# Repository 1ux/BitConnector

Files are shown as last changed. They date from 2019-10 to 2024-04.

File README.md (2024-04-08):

*„Jede Lösung eines Problems ist ein neues Problem.“ - J. W. Goehte*

# BitConnector

The BitConnector is a Complex Programmable Logic Device (CPLD) Board, optimized for hardware-based, digital prototype design on a breadboard.
The BitConnector is designed to represent a classic DIP chip in 2.54mm pitch with 2 * 20 pins. 
Configurations that are present in an HDL/schematic are transmitted via JTAG and stored permanently on the CPLD.

<table><tr>
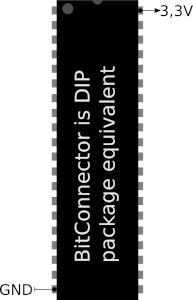
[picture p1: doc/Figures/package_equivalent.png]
BitConnector PCB layout
<td>    </td>
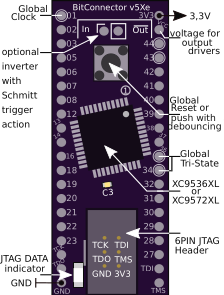
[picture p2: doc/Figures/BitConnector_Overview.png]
BitConnector
<td>    </td>
<td>   BitConnector circuit board </td>
<td>   BitConnector PCB Copper layer </td>
</tr></table>

## Usage & Documentation

Like every IC the BitConnector needs a clean operating voltage without ripple.
In practice, the following methods have proven successful:

- Protect the 3V3 Pin with 100nf and 10nf capacitors against GND.
- Keep the 3V3 and GND connections short and stable.
- Avoid long signal and test leads (up to 25 cm) to the inputs during operation.
- If you are having trouble getting a clean clock input, set „implementation template“ to „optimize density“ in Process Properties/Fitting
  or disable the special globally routed nets as described [here](https://web.archive.org/web/20210309172427/https://www.xilinx.com/support/documentation/sw_manuals/help/iseguide/mergedProjects/destech/html/cd_using_global_nets.htm)

Example experimental setup:

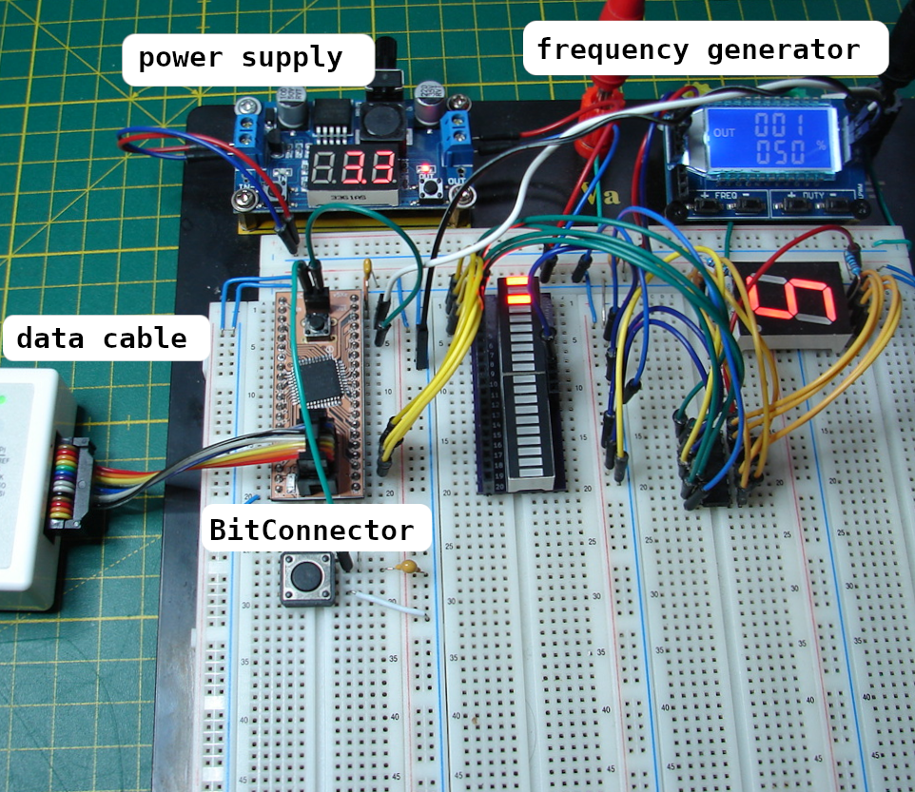
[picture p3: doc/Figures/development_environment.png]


- there is a detailed German board [documentation](doc/Board_Doc_German.pdf) :de:
- here is the preview for the [schematic](doc/schematic_v5Xe.pdf)
- files for board production have also been published in [Gerber](gerbers/gerbers_v5Xe.zip) format
- for a revision overview check: [changelog](changelog.txt)
- for all other questions, study the Kicad project.

| | | | | | |
| :- | :---: | :--- | :---: | :---: | :--- |
| **DIP-left**  | **CPLD-Pin** | **function** | **DIP-right**  | **CPLD-Pin** | **function** |
| 1  | 1 |GPIO, GCK3| 1 |  15,35 | 3V3/V<sub>ccINT</sub> |
| 2  | 2 | GPIO | 2 | 26 | VCC V<sub>ccIO</sub>  |
| 3  | 3 | GPIO | 3 | 44 | GPIO, GCK2 |
| 4  | 5 | GPIO | 4 | 43 | GPIO, GCK1 |
| 5  | 6 | GPIO | 5 | 42 | GPIO |
| 6  | 7 | GPIO | 6 | 41 | GPIO |
| 7  | 8 | GPIO | 7 | 40 | GPIO |
| 8  | 12 | GPIO | 8 | 39 | GPIO |
| 9  | 13 | GPIO | 9 | 38 | GPIO |
| 10 | 14 | GPIO | 10 | 37 | GPIO |
| 11 | 16 | GPIO | 11 | 36 | GPIO, GTS1 |
| 12 | 18 | GPIO | 12 | 34 | GPIO, GTS2 |
| 13 | 19 | GPIO | 13 | 32 | GPIO |
| 14 | 20 | GPIO | 14 | 31 | GPIO |
| 15 | 21 | GPIO | 15 | 30 | GPIO |
| 16 | 22 | GPIO | 16 | 29 | GPIO |
| 17 | 23 | GPIO | 17 | 28 | GPIO |
| 18 | 11 | TCK | 18 | 27 | GPIO |
| 19 | 24 | TDO | 19 | 9 | TDI |
| 20 |  17,25,4 | GND | 20 | 10 | TMS | |

Supplements and notes:

- **GPIO**=General Purpose In/Output, **GRS**=Global Reset, **GTS**=Global Tri-State, **GCK**=Global Clock, **TDI**=Test Data In, **TDO**=Test Data Out, **TCK**=Test Clk, **TMS**=Test Mode Select, V<sub>ccINT</sub>=Supply voltage internal logic, V<sub>ccIO</sub>=Supply voltage output driver
- Pin 33 is connected to the onboard push-button with GRS.
- With hardware debouncing, the push-button is high-active, otherwise it is low-active.

## Build

| | | | | |
| :- | :---: | :---: | :---: | :---: |
| No  | component |  value | quantity | package |
| 1 | Unpolarized capacitor | 100nF | 3 | 0603 |
| 2 | Unpolarized capacitor | 10nF | 3 | 0603 |
|  (3)  | Unpolarized capacitor | 100nF | 1 | 0603 |
|  (4)  | Resistor | 100K | 1 | 0805 |
|  (5)  | Resistor | 10K | 1 | 0805 |
| 6 | Resistor | 10K | 4 | 0805 |
| 7 | Resistor | 120 | 1 | 0805 |
| 8 | LED | blue | 1 | 1206 |
| 9 | Push button | 6 mm | 1 | THT |
| 10  | Pin Header 1x20 | 2.54 mm | 2 | vertical |
| 11  | IDC Header 2x3 | 2.54 mm | 1 | vertical |
|  (12) | Pin Socket 1x2 | 2.54 mm | 1 | vertical |
|  (13) | 74LVC2G14 | Schmitt-Tr  | 1 | SOT457 |
| 14  | XC9536XL/XC9572XL | CPLD | 1 | VQ44/VQG44  |

- The components without brackets correspond to the minimum configuration (without hardware debouncing).
- You can use the [XC9536XL](https://www.xilinx.com/support/documentation/data_sheets/ds058.pdf) or the more powerful [XC9572XL](https://www.xilinx.com/support/documentation/data_sheets/ds057.pdf) CPLD.
- The BitConverter was designed in a minimal configuration with commercially available components.
- The bracketed components are optional for hardware debouncing/Schmitt trigger action via [74LVC2G14](https://assets.nexperia.com/documents/data-sheet/74LVC2G14.pdf).
- If you make the board without hardware debouncing, please set the solderjumper J1.
- In addition to the schematic, the [Gerber](https://github.com/1ux/BitConnector/raw/master/gerbers/gerbers_v5X.zip) files for board production have also been published.

## Thanks to:

- Jeremy Heighway for mentoring English grammar and spelling.
- [Jana Weigel](https://janaweigel.wordpress.com/) for graphic design consulting, mentoring German grammar and spelling.
- [Lothar Miller](http://www.lothar-miller.de/) for PCB design consulting.
- [mikrocontroller.net](https://www.mikrocontroller.net/topic/492067) for failure analysis and life experience ;).

## Licence
This project by Michael Krause is distributed in the hope that it will be useful, but WITHOUT ANY WARRANTY.

This project is free: you can redistribute it and/or modify
it under the terms of [CC BY-SA 4.0](https://creativecommons.org/licenses/by-sa/4.0/deed.de)
Excluded from this licence is the logo(./doc/Figures/Logo.pdf).
Should you change or delete something, please remove the logo.

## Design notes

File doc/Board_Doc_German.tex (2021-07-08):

\documentclass{article}
\usepackage[utf8]{inputenc}
\usepackage[T1]{fontenc} % das Trennen der Umlaute
\usepackage[ngerman]{babel}
\usepackage{colortbl}
\usepackage{microtype}
\usepackage{graphicx}
\usepackage{grffile}
\usepackage{siunitx}  % für Einheiten
\usepackage{hyperref}
\usepackage{amsmath}
\sisetup{locale = DE,  
	separate-uncertainty,  
	range-units = brackets,  
	list-units = single,  
	per-mode=symbol-or-fraction} 
%\usepackage{subfig}
\usepackage{wrapfig}
\usepackage{tikz}
\usetikzlibrary{shapes}
\usepackage{xspace}

%-----------------------------------------------------------------------
%	BIBLIOGRAPHY
%-----------------------------------------------------------------------
\usepackage[style=numeric,sorting=none,backend=biber]{biblatex}
\addbibresource{Bibliographiedatei.bib}
%-----------------------------------------------------------------------

\graphicspath{{Figures/}}

\setlength{\parindent}{0em} 

\title{Dokumentation des BitConnector v5Xe}
\author{Michael Krause \\CC BY-SA 4.0 }

\date{\today}

\begin{document}
\maketitle
%\begin{figure}[!h]
%	\centering
%	\includegraphics[scale=0.06]{Logo}
%\end{figure}

%\thispagestyle{empty}
%\setlength{\unitlength}{1mm}
\begin{picture}(0,0)
\put(230,20){}
\end{picture} %

\section{Einführung}
Die noch immer andauernden Bemühungen der mikrokosmischen Minimierung von integriertern Schaltkreisen hat Integrationsdichten hervorgebracht, die traditionelle Schaltkreise wie einzelne Register, Zähler, ALUs oder Multiplexer vom Markt verschwinden ließen. Aus der Sicht des Endkonsumentenmarktes mag dieser Schritt folgerichtig sein, jedoch gibt es jenseits dessen noch immer das Bedürfnis auf der Register-Transfer Ebene oder darunter, Logikschaltkreise zu modellieren und zu realisieren. Dieses Bedürfnis kann beispielsweise der akademischen Lehre, dem Wunsch nach Parallelisierung oder der Vorgabe zeitkritischer Anwendungen entspringen. Obwohl es diesbezüglich eine Vielzahl von FPGAs und CPLD-Typen zur Abhilfe gibt, gestaltet sich der prototypische Aufbau auf einem Steckbrett mit Hilfe dieser Chips als nahezu unmöglich. Derartige Chips besitzen meist eine Vielzahl an Pins, die nicht im Dual in-line package (DIP) vorliegen. Der BitConnector versucht dieses Problem zu lösen.

\vspace{0.5cm}

%%Freiheitsgrade ....

\begin{wrapfigure}[14]{l}{0.50\textwidth}
		\vspace { -15pt }
	 
	\caption{BitConnector v5Xe}
	\label{fig:}
\end{wrapfigure}

Der BitConnector ist ein \textbf{C}omplex \textbf{P}rogrammable \textbf{L}ogic \textbf{D}evice, kurz \textbf{CPLD} Board, das für den  hardwarebasierten, digitalen Prototypenentwurf auf einem Steckboard optimiert wurde und zudem gesockelt auf andere Platinen aufgesetzt werden kann. Das Board ist so entworfen, dass es einen klassischen DIP Chip mit 2,54 mm Rastermaß und 2 * 20 Pins nachbildet. Konfigurationen, die etwa in einer HDL vorliegen, werden mittels JTAG übertragen und dauerhaft auf dem CPLD gespeichert.

\section{Eckdaten} 

BitConnector Board-Spezifikation
\begin{itemize}
	\item \textit{Anzahl der frei beschaltbaren Ein/Ausgänge:} \hspace{0.3cm} 33 GPIOs\footnote{\textbf{GPIO}=General Purpose In/Output, \textbf{GRS}=Global Reset, \textbf{GTS}=Global Tri-State, \textbf{GCK}=Global Clock, \textbf{TDI}=Test Data In, \textbf{TDO}=Test Data Out, \textbf{TCK}=Test Clk, \textbf{TMS}=Test Mode Select, \textbf{V\textsubscript{INT}}=Supply voltage internal logic, \textbf{V\textsubscript{IO}}=Supply voltage output driver} und ein Taster
	\item \textit{Gesamtanzahl der Pins:} \hspace{3.6cm} 2 Reihen * 20 Pins (2,54mm)
	\item \textit{kompatible CPLD-Varianten}: \hspace{2.8cm} XC95\textbf{72}XL sowie XC95\textbf{36}XL
	\item Max. Produktterme: \hspace{4.1cm} 1600 bei 72XL/800 bei~36XL
	\item \textit{IC-Package}: \hspace{5.3cm} VQ44 
\end{itemize}

Absolute, maximale Belastbarkeit:
\begin{itemize}
	\item \textit{Versorgungsspannung bezogen auf GND:} \hspace{1cm} -0,5V bis 4V
	\item \textit{IO-Pin Eingangsspannung bezogen auf GND:} \hspace{0.25cm} -0,5V bis 5,5V
	\item \textit{Max. Stromfluss bei max. 70 \si{\celsius} Chiptemp.}:\hspace{0.6cm} $\approx1,6A$ (siehe Kapitel \ref{sec:max_I})
\end{itemize}

Es wird empfohlen, Spannungen über und unter 3,3V($\pm 0,3V$) zu vermeiden!

\section{Pinbelegung BitConnector v5Xe}
\label{sec:Pins}

\begin{minipage}{0.54\textwidth}
	%\begin{table}[h]
	\begin{tabular}{c|c|c}
		DIP-links & CPLD Pin & Funktion\\
		\rowcolor[gray]{.8}	1 & 1 &	GPIO\footnotemark[1], GCK3\footnotemark[1]\\
		2 & 2 & GPIO\footnotemark[1]\\
		\rowcolor[gray]{.8}	3 & 3 & GPIO\footnotemark[1]\\
		4 & 5 & GPIO\footnotemark[1]\\
		\rowcolor[gray]{.8}	5 & 6 & GPIO\footnotemark[1]\\
		6 & 7 & GPIO\footnotemark[1]\\
		\rowcolor[gray]{.8}	7 & 8 & GPIO\footnotemark[1]\\
		8 & 12 & GPIO\footnotemark[1]\\
		\rowcolor[gray]{.8}	9 & 13 & GPIO\footnotemark[1]\\
		10 & 14 & GPIO\footnotemark[1]\\
		\rowcolor[gray]{.8}	11 & 16 & GPIO\footnotemark[1]\\
		12 &  18 & GPIO\footnotemark[1]\\
		\rowcolor[gray]{.8}	13 & 19 & GPIO\footnotemark[1]\\
		14 & 20 & GPIO\footnotemark[1]\\
		\rowcolor[gray]{.8}	15 & 21 & GPIO\footnotemark[1]\\
		16 & 22 & GPIO\footnotemark[1]\\
		\rowcolor[gray]{.8}	17 & 23 & GPIO\footnotemark[1]\\
		18 & 11 & TCK\footnotemark[1] JTAG\\
		\rowcolor[gray]{.8}	19 & 24 & TDO\footnotemark[1] JTAG\\	
		20 & 17,25,4 & GND
	\end{tabular}
	%\end{table}
\end{minipage}
\begin{minipage}{0.2\textwidth}
	\begin{tabular}{||c|c|c}
		DIP-rechts	& CPLD-Pin & Funktion\\
		\rowcolor[gray]{.8}	1		& 15,35 & 3V3/V\textsubscript{INT}\footnotemark[1] \\
		2		& 26 & 		V\textsubscript{IO}\footnotemark[1]\\
		\rowcolor[gray]{.8}	3	& 44 & GPIO, GCK2\footnotemark[1]\\
		4	& 43 & GPIO\footnotemark[1], GCK1\footnotemark[1]\\
		\rowcolor[gray]{.8}	5	& 42 & GPIO\footnotemark[1]\\
		6	& 41 & GPIO\footnotemark[1]\\
		\rowcolor[gray]{.8}	7	& 40 & GPIO\footnotemark[1]\\
		8	& 39 & GPIO\footnotemark[1]\\
		\rowcolor[gray]{.8}	9	& 38 & GPIO\footnotemark[1]\\
		10	& 37 & GPIO\footnotemark[1]\\
		\rowcolor[gray]{.8}	11	& 36 & GPIO\footnotemark[1], GTS1\footnotemark[1]\\
		12	& 34 & GPIO\footnotemark[1], GTS2\footnotemark[1]\\
		\rowcolor[gray]{.8}	13	& 32 & GPIO\footnotemark[1]\\
		14	& 31 & GPIO\footnotemark[1]\\
		\rowcolor[gray]{.8}	15	& 30 & GPIO\footnotemark[1]\\
		16	& 29 & GPIO\footnotemark[1]\\
		\rowcolor[gray]{.8}	17	& 28 & GPIO\footnotemark[1]\\
		18	& 27 & GPIO\footnotemark[1]\\
		\rowcolor[gray]{.8}	19		& 9 & TDI\footnotemark[1] JTAG\\	
		20		& 10 & TMS\footnotemark[1] JTAG
	\end{tabular}
\end{minipage}\\
\begin{minipage}{0.2\textwidth}
	\begin{tabular}{c|c|c}
		\rowcolor[gray]{.8} Taster \hphantom{\hspace*{0.38cm}} & \hphantom{\hspace*{0.55cm}} 33 \hphantom{\hspace*{0.5cm}} &  GRS, high active mit hardware debouncing, sonst low active
	\end{tabular}
\end{minipage}
\newpage

\section{Strom und Spannungsversorgung}

\subsection{Spannungsversorgnung V\textsubscript{ccINT}}
Wie bei traditionellen ICs auch, befindet sich die Betriebsspannung (V\textsubscript{ccINT}) des BitConnectors oben rechts  in Bezug zu GND (unten links).
Auf der Platine ist der V\textsubscript{ccINT} Pin mit „3V3“ beschriftet.
\\\\
\fbox{\parbox[c][0.5cm]{12cm}{V\textsubscript{ccINT} sollte 3.6V nicht übersteigen und 3V nicht unterschreiten. \autocite[3]{XC95_Spec}}}
\\\\
Der BitConnector besitzt aus Gründen der Flexibilität keinen Spannungsregler, es ist daher ratsam die Spezifikationen immer im Auge zu behalten. Ein weitere Fehlerquelle bezüglich {V\textsubscript{ccINT} ist eine unstabilisierten oder unsaubere Spannungsversorgung. In einem solchen Fall wird ein undefiniertes Verhalten bei getakteten/sequenziellen Schaltkreiskonfigurationen zu beobachten sein. 

\begin{figure}[!h]
	\begin{minipage}[!b]{.43\linewidth} % [b] => Ausrichtung an \caption
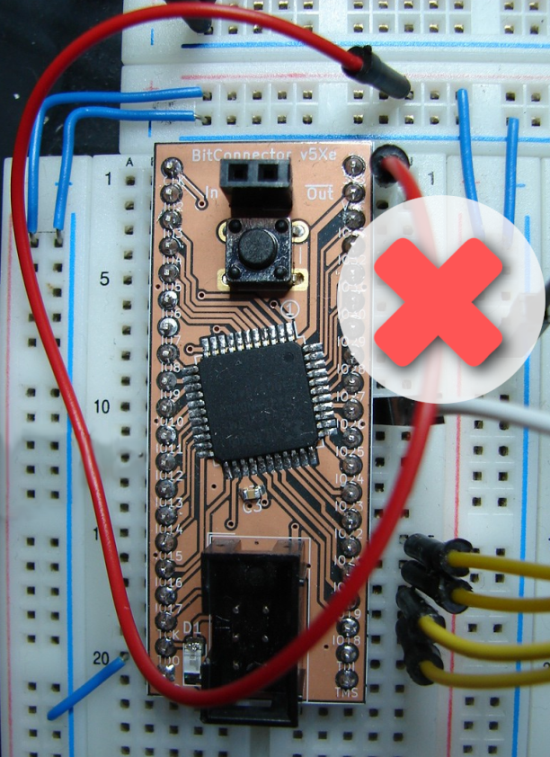
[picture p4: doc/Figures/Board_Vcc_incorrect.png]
		
		\caption{ungünstige Anbindung an die Versorgungsspannung}
		\label{fig:VCC_fail}
	\end{minipage}
	\hspace{.1\linewidth}% Abstand zwischen Bilder
	\begin{minipage}[!b]{.45\linewidth} % [b] => Ausrichtung an \caption
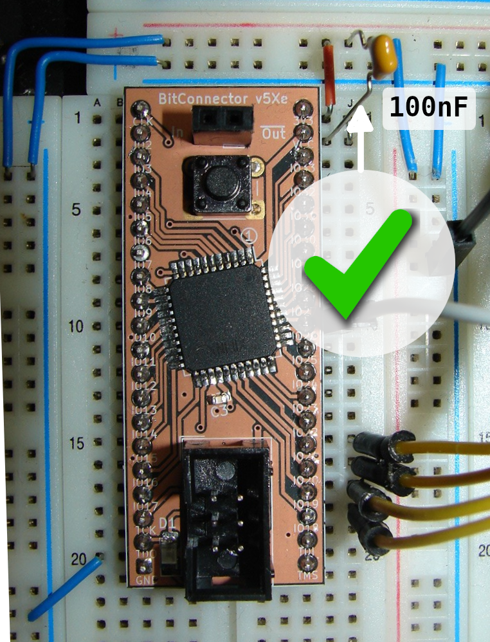
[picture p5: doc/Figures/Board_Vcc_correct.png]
		
		\caption{empfohlene Anbindung an die Versorgungsspannung}
		\label{fig:VCC_ok}
	\end{minipage}
\end{figure}

Obwohl ich nach der Xilinx Empfehlung \autocite{JTAG_Checklist} Bypass-Kondensatoren für verschiedene Frequenzbereiche auf dem BitConnector vorgesehen habe, um undefiniertem Verhalten vorzubeugen, sollten Sie immer einen zusätzlichen 100nF Kondensator direkt am 3V3 Pin des BitConnectors einsetzen (siehe Abbildung \ref{fig:VCC_ok}). Auch unnötig lange Kabel wie in Abbildung \ref{fig:VCC_fail}) sollten nach Möglichkeit vermieden werden.
%An dieser Stelle ist noch erwähnenswert, dass Sie nach \autocite[17]{XC95_maxI} einen „ stromlosen“ I/O-Pin mit einer maximalen Spannung von V\textsubscript{ccINT}+4V treiben dürfen.

\subsection{Definition der I/O Spannung über V\textsubscript{ccIO}}

Neben der Versorgungsspannung V\textsubscript{ccINT} existiert direkt darunterliegend der Pin V\textsubscript{ccIO}(siehe Kapitel \ref{sec:Pins}), welcher die Höhe der Pin-Ausgangsspannung definiert. Der V\textsubscript{ccIO} Pin ist auf der Platine mit „Vcc“ beschriftet. Sie können die Ausgangsspannung eines Pins in den Bereich zwischen 3,3V bis 2,5V über  V\textsubscript{ccIO} festlegen. Für eine Ausgangsspannung von 3,3 Volt sollte V\textsubscript{ccIO} zwischen 3V und 3,6V liegen. Wird dagegen eine Ausgangsspannung von 2,5V forciert, sollte V\textsubscript{ccIO} zwischen 2,3V und 2,7V liegen, siehe \autocite[3]{XC95_Spec}. Auf diese Weise kann die Ausgangsspannung aller Pins unabhängig von der Versorgungsspannung V\textsubscript{ccINT} eingestellt werden.

\subsection{Ausgangskennlinie eines XC9536XL CPLDs}
Sobald Sie einen GPIO-Pin des BitConnectors als Ausgang definieren und diesen mit einem Stromfluss belasten, in dem Sie beispielsweise eine LED ansteuern, sackt die Ausgangsspannung des entsprechenden Pins ab. Dieser Effekt geht auf den verwendeten CPLD zurück. Um eine Vorstellung zu erhalten, wie sich der treibende Strom zur Spannung verhält, habe ich einige stichpunktartig Messungen durchgeführt. Diese Messwerte sind in Abbildung \ref{fig:out_characteristics} mittels Bezierinterpolation zusammen gefasst und grafisch dargestellt.
Die Messreihe wurde über ein Fluke 87 III auf Pin 37 strom-/spannungsrichtig aufgenommen, V\textsubscript{ccINT} und V\textsubscript{ccIO} betrugen 3,3V. Obwohl es sich bei der Messung um einen XC9536XL CPLD handelt, ist es naheliegend, dass der XC9572XL eine sehr ähnliche Charakteristik zeigt. Verwunderlich ist, dass die Messreihe im Bereich zwischen 2V und 0V eine signifikant Abweichung (max. 10mA bei 0V) von der Xilinx-Spezifikation \autocite[6]{XC_Curves} aufweist.

\begin{figure}[!h]
	\centering
	
	\caption{Ausgangskennlinie eines XC9536XL}
	\label{fig:out_characteristics}
\end{figure}

\subsection{Maximaler Stromfluss $I_{max}$}
\label{sec:max_I}
Wer nach einem konkreten Wert bezüglich der maximal zulässigen Stromaufnahme im Datenblatt \autocite{XC95_Spec} des XC95\textbf{72}XL oder des XC95\textbf{36}XL sucht, wird keine derartige Angabe finden.
Zwar wird eine Abschätzung der zu erwartenden Stromaufnahme über eine Formel angegeben, welche die Frequenz, Anzahl der verwendeter Macrozellen u.s.w. mit einbezieht, jedoch bleibt ein maximal zulässiger Stromfluss $I_{max}$ unerwähnt. Der Hauptgrund dafür dürfte wohl an der variablen Umgebungstemperatur und in der individuell eingesetzten Kühlung des ICs liegen. Eine plausible Annahme für derartige Werte und die damit einhergehende maximale Stromaufnahme wäre von Xilinx an dieser Stelle jedoch angebracht gewesen und sei es nur, um eine erste Abschätzung zu bekommen.\\

Um eine solche Abschätzung der maximalen Stromaufnahme $I_{max}$ soll es nachfolgend gehen. Die Berechnung ist ein wenig müßig und führt über verschiedene Dokumentationen.
Zuerst wird die zu $I_{max}$ zugehörige Verlustleistung $P_d$ über folgende Ungleichung berechnet.\autocite[16]{XC95_maxI}: 
\begin{center}
	$T_{jmax} < (\Theta_{JC}*P_d)+T_a$
\end{center}

kurze Variablenbeschreibung:

\begin{itemize}
	\item $T_{jmax}$: Maximaltemperatur in \si{\celsius} bezogen auf das IC Package \\(70 \si{\celsius} für Kunststoff) \autocite[54]{Device_pkg}
	\item $\Theta_{JC}$: Wärmeflusswiderstand in $\si{\celsius}/[W]$ zwischen der Chipoberfläche und der Oberfläche des Gehäuses \autocite[53]{Device_pkg} (8.2 \si{\celsius}/W für 72/36 in VQ44)
	\item $P_d$: tatsächliche Leistung in [W]att, welche sich in Hitze äußert \autocite[16]{XC95_maxI}
	\item $T_a$: Umgebungstemperatur in \si{\celsius} (50 \si{\celsius})
\end{itemize}

Um $\Theta_{JC}$ nicht aufwendig durch eine Messung bestimmen zu müssen, bietet Xilinx eine Datenbank an \autocite{ThetaJC}. Für den XC95\textbf{72}XL/XC95\textbf{36}XL liegt dieser Wert bei 8.2 \si{\celsius}/W im VQ44 Package.\\\\
Zudem schlägt Xilinx für $T_{jmax}$ einen Wert von 70 \si{\celsius} für Kunststoffgehäuse vor. Dieser Wert ist ebenfalls für beide möglichen Chipvarianten angebracht.\\\\
Die Umgebungstemperatur des Chips wird vorsichtig mit 50 \si{\celsius} veranschlagt.\\\\
Ausgehend von diesen Annahmen berechnet sich die Verlustleistung nach \autocite[16]{XC95_maxI} wie folgt:

\begin{center}
	$70 \si{\celsius} = (8.2 \si{\celsius}/W*P_d)+50 \si{\celsius} \Rightarrow$\\
	$20 \si{\celsius} = (8.2 \si{\celsius}/W*P_d)\Rightarrow$\\
	$2,439 W = P_d$\\ %\vspace{0.5cm}
\end{center}

Weiter ist notwendig, die Verlustleistung in $P_d = P_{ddesign} + P_{dIO}$ aufzuschlüsseln.
$P_{ddesign}$ repräsentiert hierbei die Leistung ohne eine Last, also die Leistung die der Chip selbst für sich beansprucht, ohne einen Ausgang zu treiben. Dieser Wert sollte gemessen werden und lautet für den BitConnector rund 40mW. Wird dieser Wert aus Sicherheitsgründen verdoppelt, ist von rund 80mW auszugehen.\\\\
Somit gilt: 
\begin{center}
	$2,439 W = 80mW + P_{dIO}$
\end{center}

Um schlussendlich auf den gesuchten Wert $I_{max}$ zu kommen, wird folgende Formel nach \autocite[16]{XC95_maxI} herangezogen:

\begin{center}
	$I_{max} * (VCC - 1,85V) = P_d - P_{ddesign}$
\end{center}

Sicher fragen Sie sich, woher die 1,85V herstammen. Dieser Wert wurde über die Kennlinienfelder in \autocite[6]{XC_Curves} abgelesen und sagt aus, dass bei einem Stromfluss von 30mA, die Spannung des entsprechenden Ausgangs auf 1,85V absinkt.

Daraus folgt: 
\begin{center}
	$I_{max} * (3,3V - 1,85V) = 2,439 W - 0.08W \rightarrow$\\
	\underline{\underline{$I_{max}\approx 1,63A $}}
\end{center}
Der Wert $I_{max}$ sagt aus, dass bei einer I/O-Spannung von 1,85V und einer Stromstärke von 30mA pro Ausgang, eine Gesamtstromstärke von 1,63A erreicht wird. Hierbei liegt die Chiptemperatur $\leq $ der als kritisch angenommenen 70$\si{\celsius}$. Auffällig ist, dass die 1,63A in dieser Konstellation im Bitconnector nie erreicht werden können, da dieser nur 34 mögliche Ausgänge bietet. Mit den getroffenen Annahmen ist jedoch die Versorgung von $\frac{1,63A}{0,03A}\approx54$ Ausgänge möglich.\\\\
Bitte verlassen Sie sich nicht auf die angegebene Berechnung und überprüfen Sie auch die Quellen. Sollten Sie einen Fehler finden, wäre ich Ihnen sehr dankbar, wenn Sie mich diesbezüglich kontaktieren.

\newpage

\section{Hardware Entprellung}
Gelegentlich ist es sehr hilfreich, eine getaktete, sequenzielle Schaltung schrittweise über das Drücken eines Taster zu durchlaufen. Leider erzeugen so ziemlich alle handelsüblichen Taster ein sogenanntes „Prellen“, da die Kontakte des Tasters nicht sauber schließen oder öffnen. Ein solches Prellen führt zu einer unvorhersagbaren Abfolge von Signalimpulsen. Schauen Sie sich hierfür einmal die Abbildung \ref{fig:prellen_1} genauer an. 

\begin{figure}[!h]
	\centering
	
	\caption{Tastendruck am BitConnector ohne Entprellung}
	\label{fig:prellen_1}
\end{figure}

Hier wird ein einfacher Tastendruck über ein Oszillogramm grafisch veranschaulicht. Interessant ist der Bereich der fallende Flanke ab 80 Millisekunden, also ungefähr an der Stelle, an dem der Taster wieder losgelassen wird. Wenn Sie diesen Bereich kritisch betrachten, werden Sie bemerken, dass es bei ungefähr 92 Millisekunden bereits einen ungewollten Wechsel der Signalflanke gibt. Lassen Sie uns diesen Bereich mit der „Lupe“ in Abbildung \ref{fig:prellen_2} etwas näher betrachten.

\begin{figure}[!h]
	\centering
	
	\caption{Nahaufnahme der fallenden Flanke aus Abbildung \ref{fig:prellen_1}}
	\label{fig:prellen_2}
\end{figure}

Es ist erkennbar, dass der Signalpegel in Abbildung \ref{fig:prellen_2} bereits bei ungefähr 2 Millisekunden hin und herspringt und somit mehrere Flanken erzeugt. Diese Signalflanken sind bei sogenannten sequenziellen Schaltungen, die auf fallende oder steigende Flanken reagieren, problematisch. Eine einfache Zählerschaltung, die mit jedem Tastendruck „1“ hinzu addiert, wird augenscheinlich nicht funktionieren. So scheint es, als würde der Zähler einzelne Zählschritte beim Drücken oder Loslassen des Tasters überspringen. Mit einem höherwertigen Oszilloskop ließe sich der problematische Bereich noch näher untersuchen, was weitere Taktwechsel und somit weitere Zählimpulse mit nur einem Tastendruck aufdecken könnte. 
Da Sie bei CPLDs prinzipiell mit Ihren Flip-Flop-Ressourcen sehr haushalten müssen und keinen Mikrocontroller für eine Entprellroutine haben, wurde für den BitConnector eine Hardwareentprellung vorgesehen. 

\newpage

Sollte Ihr BitConnector mit dem 74LVC2G14 IC bestückt sein, so ist auch der Taster SW1 automatisch entprellt. Ein Tastendruck sollte dann wie in Abbildung \ref{fig:prellen_3} eine einzige und saubere Flanke erzeugen. 

\begin{figure}[!h]
	\centering
	
	\caption{Tastendruck am BitConnector mit Hardware-Entprellung}
	\label{fig:prellen_3}
\end{figure}

Sollte dies nicht der Fall sein, so können Sie auf Grundlage der nachfolgenden Erläuterungen eine eigene Hardwareentprellung nachschalten.

\subsection{Prinzip der Hardwareentprellung}
Da die vom Menschen erzeugten Frequenzen der Tastendrücke im Vergleich zum Prellen des Tasters sehr niedrig sind, ist es naheliegend einen Tiefpassfilter in Form eines RC-Gliedes dem Taster vorzuschalten. 
Dieser Tiefpass filtert die hochfrequenten Anteile des Prellens aus dem Tastendruck heraus. Das Prellen ist verschwunden. Es entsteht allerdings ein neues Problem. Da ein RC-Glied naturgemäß aus einem Widerstand und einem Kondensator besteht, durchläuft dieser Kondensator eine Ladespannung, die dem natürlichen Logarithmus sehr nahe kommt \autocite{RC}. Eine digitale Schaltung auf CMOS-Basis benötigt jedoch eine steile Signalflanke, also beispielsweise einen Signalwechsel von 0V auf direkt 3,3V. Andernfalls besteht die Gefahr, dass die Schaltung eine gewisse Zeit einen undefinierten Zustand annimmt. Auf Transistorebene kann dieser undefinierte Zustand gefährlich sein, da eine Transistorkonstellation, die es theoretisch so nicht geben sollte, plötzlich anfangen kann, den Strom zu leiten. Zudem werden Sie immer noch keine Freude beim auswerten des Tastenimpuls haben. Es ist daher nachdrücklich anzuraten, diese undefinierten Signalzustände in digitalen Schaltungen zu vermeiden. Dies geschieht hier mit Hilfe eines Schmitt-Triggers. Der Schmitt-Trigger soll verkürzt dargestellt, den undefinierten Spannungsbereich vor dem digitalen Eingang einer Schaltung über eine sogenannte „charakteristische Hysterese“ vermeiden. Sie können sich den Schmitt-Trigger in diesem Fall als den „eigentlichen Schalter“ vorstellen, der an seinem Ausgang immer einen steilen Pegel schaltet, während er am Eingang eine Kondenstorkennlinie „sieht“.
%Grafiken (Auch Schaltplan) und Berechnungen einfügen.

\section{Entwicklungsumgebung}

Momentan gibt es noch keine vollumfängliche und freie \autocite{FSF} Entwicklungsumgebung für Xilinx CPLDs, weshalb ich auf proprietäre Software der Firma Xilinx zurückgreifen muss.
Fraglicherweise bietet Xilinx in seiner aktuellen Entwicklungsumgebung „Vivado“ keine Unterstützung für CPLDs an, siehe \autocite[17]{Vivado}. Dennoch ist es möglich, mit der älteren Design Suite „ISE“, Xilinx CPLDs problemlos zu konfigurieren.
Mit einer Registrierung bei Xilinx erhalten Sie eine kostenlose Lizenz, mit derer Sie die ISE-Demo-Version auf eine Webpack-Version \autocite{ISE-Web} freischalten können. Diese Lizenz ist ausreichend, um alle CPLDs der XC9500 Serie ohne Einschränkungen zu konfigurieren.

\section{Die JTAG Schnittstelle via 6 Pin IDC-Header}

Für die Übertragung der HDL Konfigurationsdateien auf den BitConnector ist ein 6 Pin IDC-Stecker (JTAG Schnittstelle) im 2.54mm Rastermaß vorgesehen. Die 4 aktiven JTAG-Leitungen zur Datenübertragung sind:

\begin{enumerate}
	\item Pin TCK = Test Clock
	\item Pin TDI = Test Data In
	\item Pin TDO = Test Data Out
	\item Pin TMS = Test Mode Select
\end{enumerate}

\begin{figure}[!h]
	\centering
	
	\caption{Draufsicht JTAG Pin-Header (6 way IDC male connector)}
	\label{fig:pinheader}
\end{figure}

\newpage

Die Abbildung \ref{fig:pinheader} zeigt die Draufsicht dieses Steckers, welcher auf dem Board verlötet ist.
Innerhalb dieser Abbildung erkennen Sie eine „1“, die den ersten Pin markiert. Dieser Pin ist zur Orientierung dem JTAG Test-Takt zugeordnet. Um die Anfertigung eines eigenen Programmierkabels zu erleichtern, wird nachfolgend auch das passende Datenkabel illustriert. Ich möchte Sie ermutigen, die Anfertigung eines eigenen Kabels nicht zu fürchten. Die Minimalausrüstung sehen sie in Abbildung \ref{fig:cable_equipment}

\begin{figure}[!h]
	\centering
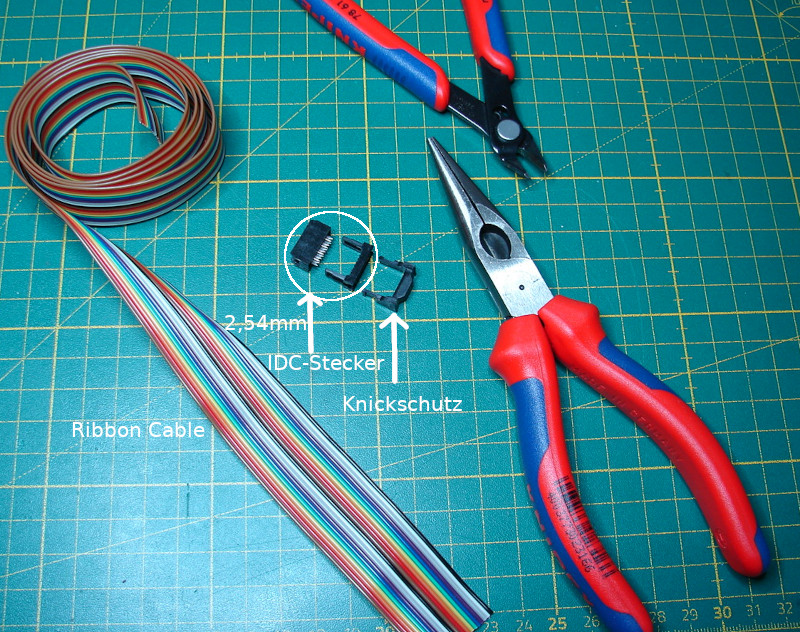
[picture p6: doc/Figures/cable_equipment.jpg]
	
	\caption{Werkzeug und Ribbon Cable + IDC-Stecker zum selber crimpen}
	\label{fig:cable_equipment}
\end{figure}

Da es mehrere Programmiergerät gibt, existieren somit mehrere Stecker-Möglichkeiten und Adapter.  In Abbildung \ref{fig:data_cable} erkennen Sie ein mögliches Datenkabel vom BitConnector zum Programmiergerät. Anders als in Abbildung \ref{fig:pinheader}, ist der 6 Pin Connector diesmal als Buchse ausgeführt und somit gespiegelt.

\begin{figure}[!h]
	\centering
	
	\caption{Programmierkabel HW-RIBBON14 zu 6 Pin IDC female}
	\label{fig:data_cable}
\end{figure}

Bei dem HW-RIBBON14 female connector hat sich Xilinx für eine eher exotische Buchse entschieden. Die Kette des Datenkabels sieht abstrakt zusammen gefasst folgendermaßen aus:
\vspace{0.5cm}
\begin{center}
	PC<->USB-Kable<->Programmierer<->Programmierkabel<->BitConnector
\end{center}

\vspace{0.5cm}

\newpage

Falls Sie kein passendes Kabel zur Hand haben, können Sie die herausgeführten JTAG Pins von den beiden Stiftleisten über ein Steckbrett abgreifen(rote Markierung).

\begin{figure}[!h]
	\centering
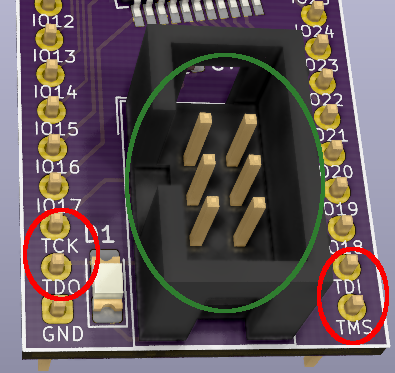
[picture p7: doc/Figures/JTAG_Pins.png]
	
	\caption{Die JTAG Schnittstelle, einmal rot umkreist als Stiftleisten und grün umkreist als IDC Header ausgeführt}
	\label{fig:JTAG_Pins}
\end{figure}

Sofern Sie mehrere BitConnectoren auf einer Platine gesockelt haben, bieten sich die Pins der Stiftleisten ebenfalls an, um die CPLDs mit nur einer herausgeführten Schnittstelle sequenziell zu konfigurieren.
\subsection{JTAG Programmiergerät}
Für die Ansteuerung der JTAG-Schnittstelle wird ein Programmiergerät benötigt. 
Hier gibt es mehrere Lösungen mit unterschiedlichen Funktionsumfang. Verbreitet sind 4 Versionen des Xilinx Platform Cable USB I/II. Dabei entfallen bereits 3 Versionen auf das Platform Cable I: 
\begin{itemize}
	\item \textbf{DLC9G} (neuste Version bezüglich Platform Cable I)
	\item \textbf{DLC9LP} (Vorgänger des DLC9G)
	\item \textbf{DLC9} (älteste Version)
\end{itemize}

\newpage

Zu diesen 3 Versionen schreibt Xilinx u.a.: „\textit{The DLC9G and legacy DLC9LP cable models draw less than 100 mA from the host USB port. The legacy DLC9 cable model requires 230 mA to operate in USB 2.0 Hi-Speed mode or 150 mA to operate in USB 2.0/1.1 full-speed mode.}“ \autocite[2]{Platform_Cable}\\\\
Das Xilinx Platform Cable USB II wird momentan unter der Versionsbezeichnung „\textbf{DLC10}“ gehandelt.
Die hohen Verbreitung dieser Programmiergeräte hat dazu beigetragen, dass es selbige auch als preisgünstige Nachbauten von anderen Herstellern zu einem Zehntel des Preises gibt.

\begin{figure}[!h]
	\centering
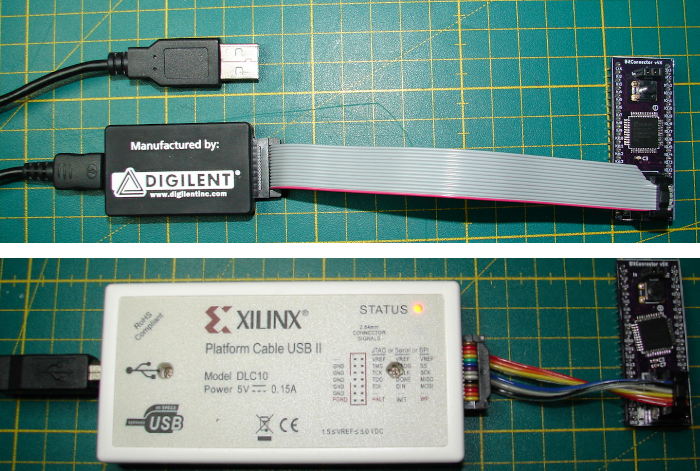
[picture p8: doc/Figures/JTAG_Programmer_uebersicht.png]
	
	\caption{oben: XUP USB-JTAG Programming Cable
		\\\hspace*{2cm} unten: Platform Cable USB II DLC10}
	\label{fig:JTAG_Cable}
\end{figure}

Als Alternative zum „Platform Cable I/II“ existiert eine kleine und günstigere Variante aus dem „Xilinx University Program“ dass die Bezeichnung „XUP USB-JTAG Programming Cable“ trägt. Sie können es nachfolgend in Abbildung \ref{fig:JTAG_Cable} erkennen. Allerdings scheint diese Variante mit dem heutigen Preisverfall des Platform Cables I/II wenig attraktiv zu sein. 
Der Vollständigkeit halber soll an dieser Stelle noch das \textbf{DLC7}/Parallel Cable IV erwähnt werden, dass jedoch in der neuen Entwicklungsumgebung von Xilinx/Vivado nicht mehr unterstützt wird \autocite{AR_54136} und aufgrund der „ausgestorbenen“ parallelen Schnittstelle bei Anwendern ebenfalls nur mehr selten anzutreffen sein dürfte. Wenn Sie keinen Wert auf Zusatzfunktionen wie „SPI PROM Support, ChipScope oder AES-Cryptographic“ legen, sollte die Wahl des Programmers eine untergeordnete Rolle spielen.

\newpage

\subsection{Offene JTAG Hardware-/Softwarelösungen für Xilinx}
Es gibt einige Projekte, die sich darum bemühen, alternative und offene JTAG Hardware-/Softwarelösungen für Xlinix Produkte anzubieten.
Um ein CPLD/FPGA zu konfigurieren, wird ein Mikrocontroller (JTAG-Programmiergerät) benötigt, der den JTAG Standard „IEEE 1149.1“ und eventuelle herstellerspezifische Abweichungen implementiert. 
Um mit diesem Mikrocontroller kommunizieren zu können, wird weiter eine PC-Software (JTAG Client) benötigt, welche die HDL synthetisierte Konfiguration (im XSVF Format) an diesen Mikrocontroller überträgt. Der Mikrocontroller nimmt letztlich über das vom PC aus übertragene XSVF Format die Konfiguration des CPLD/FPGA mittels JTAG vor.

\begin{figure}[!h]
	\centering
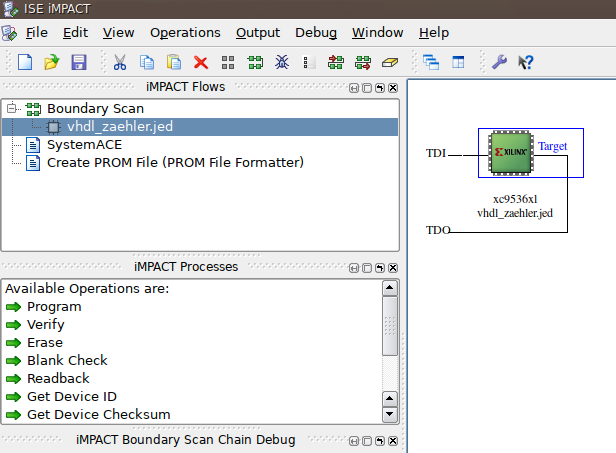
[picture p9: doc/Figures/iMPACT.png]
	
	\caption{Das proprietäre iMPACT überträgt und verifiziert die HDL Konfiguration (über ein JTAG Programmiergerät) auf dem CPLD oder FPGE}
	\label{fig:iMPACT}
\end{figure}

Um aber auf die offenen Alternativen hinzuweisen, soll hier die Lib(X)SVF von Clifford Wolf\autocite{LibXSVF} Erwähnung finden. Lib(X)SVF ist eine C-Bibliothek zur Implementierung/Umsetzung von JTAG-Programmiergeräten mittels XSVF/SVF Format. Eine konkrete Implementierung ist beispielsweise das „clujtag“ Projekt, wobei clujtag \autocite{clujtag} die Firmware eines einfachen AVR basierten Programmiergeräts bildet und clujtag-client \autocite{clujtag-client} eine kommandozeilenbasierte Alternative zu Xilnix iMPACT darstellt.
In welchen Umfang diese und andere Projekte heute tragfähig sind, kann ich bisher nicht einschätzen.

\newpage
\printbibliography
\end{document}

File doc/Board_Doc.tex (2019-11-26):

\documentclass{article}
\usepackage[utf8]{inputenc}
\usepackage[T1]{fontenc} % das Trennen der Umlaute
\usepackage[ngerman]{babel}
\usepackage{colortbl}
\usepackage{microtype}
\usepackage{graphicx}
\usepackage{grffile}
\usepackage{siunitx}  % für Einheiten
\usepackage{hyperref}
\usepackage{amsmath}
\sisetup{locale = DE,  
	separate-uncertainty,  
	range-units = brackets,  
	list-units = single,  
	per-mode=symbol-or-fraction} 
%\usepackage{subfig}
\usepackage{wrapfig}
\usepackage{tikz}
\usetikzlibrary{shapes}
\usepackage{xspace}

%-----------------------------------------------------------------------
%	BIBLIOGRAPHY
%-----------------------------------------------------------------------
\usepackage[style=numeric]{biblatex}
\addbibresource{Bibliographiedatei.bib}
%-----------------------------------------------------------------------

\graphicspath{{Figures/}}

\setlength{\parindent}{0em} 

\title{Dokumentation des BitConnector v4X}
\author{Michael Krause \\CC BY-SA 4.0 (except logo)}

\date{\today}

\begin{document}
\maketitle
%\begin{figure}[!h]
%	\centering
%	\includegraphics[scale=0.06]{Logo}
%\end{figure}

%\thispagestyle{empty}
%\setlength{\unitlength}{1mm}
\begin{picture}(0,0)
\put(270,38){}
\end{picture} %

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

\vspace{0.5cm}

%%Freiheitsgrade ....

\begin{wrapfigure}[14]{l}{0.50\textwidth}
		\vspace { -15pt }
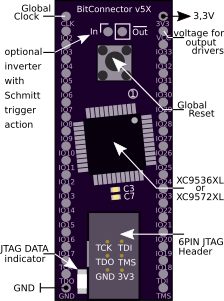
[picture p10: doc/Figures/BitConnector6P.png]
	 
	\caption{BitConnector v4X}
	\label{fig:}
\end{wrapfigure}

Der BitConnector ist ein \textbf{C}omplex \textbf{P}rogrammable \textbf{L}ogic \textbf{D}evice, kurz \textbf{CPLD} Board, das für den  hardwarebasierten, digitalen Prototypenentwurf auf einem Steckboard optimiert wurde und zudem gesockelt auf andere Platinen aufgesetzt werden kann. Das Board ist so entworfen, dass es einen klassischen DIP Chip mit 2,54 mm Rastermaß und 2 * 20 Pins nachbildet. Konfigurationen, die etwa in einer HDL vorliegen, werden mittels JTAG übertragen und dauerhaft auf dem CPLD gespeichert.

\section{Eckdaten} 

BitConnector Board-Spezifikation
\begin{itemize}
	\item \textit{Anzahl der frei beschaltbaren Ein/Ausgänge:} \hspace{0.3cm} 33
	\item \textit{Gesamtanzahl der Pins:} \hspace{3.6cm} 2 Reihen * 20 Pins (2,54mm)
	\item \textit{kompatible CPLD-Varianten}: \hspace{2.8cm} XC95\textbf{72}XL sowie XC95\textbf{36}XL
	\item Max. Produktterme: \hspace{4.1cm} 1600 bei 72XL/800 bei~36XL
	\item \textit{IC-Package}: \hspace{5.3cm} VQ44 
\end{itemize}

Absolute, maximale Belastbarkeit:
\begin{itemize}
	\item \textit{Versorgungsspannung bezogen auf GND:} \hspace{1cm} -0,5V bis 4V
	\item \textit{Eingangsspannung bezogen auf GND:} \hspace{1.45cm} -0,5V bis 5,5V
	\item \textit{Max. Stromfluss bei max. 70 \si{\celsius} Chiptemp.}:\hspace{0.6cm} $\approx1,6A$ (siehe Kapitel \ref{sec:max_I})
\end{itemize}

Es wird empfohlen, Spannungen über und unter 3,3V($\pm 0,3V$) zu vermeiden!

\section{Pinbelegung BitConnector v3X}
\label{sec:Pins}

\begin{minipage}{0.55\textwidth}
	%\begin{table}[h]
	\begin{tabular}{l|c|c|l}
		Nr & DIP-links	& CPLD-Pin & Bemerkung\\
		\rowcolor[gray]{.8}	1 & CLK		& 1 &	GCK3\\
		2 & IO2		& 2 &\\
		\rowcolor[gray]{.8}	3 & IO3		& 3 &\\
		4 & IO4		& 5 &\\
		\rowcolor[gray]{.8}	5 & IO5		& 6 &\\
		6 & IO6		& 7 &\\
		\rowcolor[gray]{.8}	7 & IO7		& 8 &\\
		8 & IO8		& 12 &\\
		\rowcolor[gray]{.8}	9 & IO9		& 13 &\\
		10 & IO10	& 14 &\\
		\rowcolor[gray]{.8}	11 & IO11	& 16 &\\
		12 & IO12	& 18 &\\
		\rowcolor[gray]{.8}	13 & IO13	& 19 &\\
		14 & IO14	& 20 &\\
		\rowcolor[gray]{.8}	15 & IO15	& 21 &\\
		16 & IO16	& 22 &\\
		\rowcolor[gray]{.8}	17 & IO17	& 23 &\\
		18 & TCK		& 11 &	JTAG\\
		\rowcolor[gray]{.8}	19 & TDO		& 24 &	JTAG\\	
		20 & GND		& 17,25,4 & 	 
	\end{tabular}
	%\end{table}
\end{minipage}
\begin{minipage}{0.2\textwidth}
	\begin{tabular}{||c|c|l}
		DIP-rechts	& CPLD-Pin & Bemerkung\\
		\rowcolor[gray]{.8}	3V3		& 15,35 &	V\textsubscript{ccINT} \\
		VCC		& 26 & 		V\textsubscript{ccIO}\\
		\rowcolor[gray]{.8}	IO33	& 44 &		GCK2\\
		IO32	& 43 &		GCK1\\
		\rowcolor[gray]{.8}	IO31	& 42 &\\
		IO30	& 41 &\\
		\rowcolor[gray]{.8}	IO29	& 40 &\\
		IO28	& 39 &\\
		\rowcolor[gray]{.8}	IO27	& 38 &\\
		IO26	& 37 &\\
		\rowcolor[gray]{.8}	IO25	& 36 &		GTS1\\
		IO24	& 34 &							GTS2\\
		\rowcolor[gray]{.8}	IO23	& 32 &\\
		IO22	& 31 &\\
		\rowcolor[gray]{.8}	IO21	& 30 &\\
		IO20	& 29 &\\
		\rowcolor[gray]{.8}	IO19	& 28 &\\
		IO18	& 27 &\\
		\rowcolor[gray]{.8}	TDI		& 9 &		JTAG\\	
		TMS		& 10 & 		JTAG 
	\end{tabular}
\end{minipage}
\\\\\\
Pin 33 ist an dem Taster SW1 fest verdrahtet, zudem ist Pin 33 auch GRS
(GSR=Global Reset, GTS=Global Tri-State, GCK=Global Clock).
%GPIO (General Purpose Input/Output)
\newpage

\section{Strom und Spannungsversorgung}

\subsection{Spannungsversorgnung VCC\textsubscript{INT}}
Wie bei traditionellen ICs auch, befindet sich die Betriebsspannung (VCC\textsubscript{INT}) des BitConnectors oben rechts  in Bezug zu GND (unten links).
\\\\
Die Betriebsspannung sollte 3.6V nicht übersteigen und 3V nicht unterschreiten. \autocite[3]{XC95_Spec}
\\\\
Es wurde bewusst auf einen Spannungsregler verzichtet, um den zu treibenden Ausgangsstrom nicht zu begrenzen. Diese Entscheidung schafft zwar Flexibilität, verlagert aber die Verantwortung auf eine korrekte Spannungsversorgung auf die externe Peripherie.\\
An dieser Stelle ist noch erwähnenswert, dass Sie nach \autocite[17]{XC95_maxI} einen „ stromlosen“ I/O-Pin mit einer maximalen Spannung von VCC\textsubscript{INT}+4V treiben dürfen.

\subsection{Definition der I/O Spannung über VCC\textsubscript{IO}}

Neben der Versorgungsspannung VCC\textsubscript{INT} existiert direkt darunterliegend der Pin VCC\textsubscript{IO}(siehe Kapitel \ref{sec:Pins}), welcher die Höhe der Pin-Ausgangsspannung definiert. Sie können die Spannung der Ausgänge bei einem h-Pegel auf 3,3V oder auf 2,5V setzen. Für eine Ausgangsspannung von 3,3 Volt, sollte VCC\textsubscript{IO} zwischen 3V und 3,6V liegen. Wird dagegen eine Ausgangsspannung von 2,5V forciert, sollte VCC\textsubscript{IO} zwischen 2,3V und 2,7V liegen \autocite[3]{XC95_Spec}

\subsection{Ausgangskennlinie eines XC9536XL CPLDs}
Sobald Sie einen Pin des BitConnectors mit einem Stromfluss belasten, in dem Sie beispielsweise eine LED ansteuern, sackt die Ausgangsspannung des entsprechenden I/O-Pins ab. Dieser Effekt geht auf den verwendeten CPLD zurück. Um nun eine Vorstellung zu erhalten, wie sich der treibende Strom zur Spannung verhält, hat der Autor einige stichpunktartig Messungen durchgeführt. Diese Messwerte sind in Abbildung \ref{fig:out_characteristics} mittels Bezierinterpolation grafisch dargestellt.
Die Messreihe wurde über ein Fluke 87 III , strom-/spannungsrichtig aufgenommen, VCC\textsubscript{INT} und VCC\textsubscript{IO} betrugen 3,3V, IO33 (CPLD Pin 44) war der (einzige) belastete Ausgang. Obwohl es sich bei der Messung um einen XC9536XL CPLD handelt, ist es naheliegend, dass der XC9572XL eine sehr ähnliche Charakteristik zeigt. Verwunderlich ist, dass die Messreihe teilweise signifikant von der Xilinx-Spezifikation \autocite[6]{XC_Curves} abweicht.  Dennoch wurde in Kapitel \ref{sec:max_I} auf die von Xilinx veröffentlichte Spezifikation zurück gegriffen.

\newpage

\begin{figure}[!h]
	\centering
	
	\caption{Ausgangskennlinie eines XC9536XL}
	\label{fig:out_characteristics}
\end{figure}

\subsection{Maximaler Stromfluss $I_{max}$}
\label{sec:max_I}
Wer nach einem konkreten Wert bezüglich der maximal zulässigen Stromaufnahme im Datenblatt \autocite{XC95_Spec} des XC95\textbf{72}XL oder des XC95\textbf{36}XL sucht, wird keine derartige Angabe finden.
Zwar wird eine Abschätzung der zu erwartenden Stromaufnahme über eine Formel angegeben, welche die Frequenz, Anzahl der verwendeter Macrozellen u.s.w. mit einbezieht, jedoch bleibt ein maximal zulässiger Stromfluss $I_{max}$ unerwähnt. Der Hauptgrund dafür dürfte wohl an der variablen Umgebungstemperatur und in der individuell eingesetzten Kühlung des ICs liegen. Eine plausible Annahme für derartige Werte und die damit einhergehende maximale Stromaufnahme wäre von Xilinx an dieser Stelle jedoch angebracht gewesen und sei es nur, um eine erste Abschätzung zu bekommen.\\

Um eine solche Abschätzung der maximalen Stromaufnahme $I_{max}$ soll es nachfolgend gehen. Die Berechnung ist ein wenig müßig und führt über verschiedene Dokumentationen.
Zuerst wird die zu $I_{max}$ zugehörige Verlustleistung $P_d$ über folgende Ungleichung berechnet.\autocite[16]{XC95_maxI}: 
\begin{center}
	$T_{jmax} < (\Theta_{JC}*P_d)+T_a$
\end{center}

\newpage

kurze Variablenbeschreibung:

\begin{itemize}
	\item $T_{jmax}$: Maximaltemperatur in \si{\celsius} bezogen auf das IC Package \\(70 \si{\celsius} für Kunststoff) \autocite[54]{Device_pkg}
	\item $\Theta_{JC}$: Wärmeflusswiderstand in $\si{\celsius}/[W]$ zwischen der Chipoberfläche und der Oberfläche des Gehäuses \autocite[53]{Device_pkg} (8.2 \si{\celsius}/W für 72/36 in VQ44)
	\item $P_d$: tatsächliche Leistung in [W]att, welche sich in Hitze äußert \autocite[16]{XC95_maxI}
	\item $T_a$: Umgebungstemperatur in \si{\celsius} (50 \si{\celsius})
\end{itemize}

Um $\Theta_{JC}$ nicht aufwendig durch eine Messung bestimmen zu müssen, bietet Xilinx eine Datenbank an \autocite{ThetaJC}. Für den XC95\textbf{72}XL/XC95\textbf{36}XL liegt dieser Wert bei 8.2 \si{\celsius}/W im VQ44 Package.\\\\
Zudem schlägt Xilinx für $T_{jmax}$ einen Wert von 70 \si{\celsius} für Kunststoffgehäuse vor. Dieser Wert ist ebenfalls für beide möglichen Chipvarianten angebracht.\\\\
Die Umgebungstemperatur des Chips wird vorsichtig mit 50 \si{\celsius} veranschlagt.\\\\
Ausgehend von diesen Annahmen berechnet sich die Verlustleistung nach \autocite[16]{XC95_maxI} wie folgt:

\begin{center}
	$70 \si{\celsius} = (8.2 \si{\celsius}/W*P_d)+50 \si{\celsius} \Rightarrow$\\
	$20 \si{\celsius} = (8.2 \si{\celsius}/W*P_d)\Rightarrow$\\
	$2,439 W = P_d$\\ \vspace{0.5cm}
\end{center}
	Weiter ist notwendig, die Verlustleistung in $P_d = P_{ddesign} + P_{dIO}$ aufzuschlüsseln.
$P_{ddesign}$ repräsentiert hierbei die Leistung ohne eine Last, also die Leistung die der Chip selbst für sich beansprucht, ohne einen Ausgang zu treiben. Dieser Wert sollte gemessen werden und lautet für den BitConnector rund 40mW. Wird dieser Wert aus Sicherheitsgründen verdoppelt, ist von rund 80mW auszugehen.\\\\
Somit gilt: 
\begin{center}
	$2,439 W = 80mW + P_{dIO}$
\end{center}

Um schlussendlich auf den gesuchten Wert $I_{max}$ zu kommen, wird folgende Formel nach \autocite[16]{XC95_maxI} herangezogen:

\begin{center}
	$I_{max} * (VCC - 1,85V) = P_d - P_{ddesign}$
\end{center}

Sicher fragen Sie sich, woher die 1,85V herstammen. Dieser Wert wurde über die Kennlinienfelder in \autocite[6]{XC_Curves} abgelesen und sagt aus, dass bei einem Stromfluss von 30mA, die Spannung des entsprechenden Ausgangs auf 1,85V absinkt.

Daraus folgt: 
\begin{center}
	$I_{max} * (3,3V - 1,85V) = 2,439 W - 0.08W \rightarrow$\\
	\underline{\underline{$I_{max}\approx 1,63A $}}
\end{center}
Der Wert $I_{max}$ sagt aus, dass bei einer I/O-Spannung von 1,85V und einer Stromstärke von 30mA pro Ausgang, eine Gesamtstromstärke von 1,63A erreicht wird. Hierbei liegt die Chiptemperatur $\leq $ der als kritisch angenommenen 70$\si{\celsius}$. Auffällig ist, dass die 1,63A in dieser Konstellation im Bitconnector nie erreicht werden können, da dieser nur 34 mögliche Ausgänge bietet. Mit den getroffenen Annahmen ist jedoch die Versorgung von $\frac{1,63A}{0,03}\approx54$ Ausgänge möglich.\\\\
Bitte verlassen Sie sich nicht auf die angegebene Berechnung und überprüfen Sie auch die Quellen. Sollten Sie einen Fehler finden, wäre ich Ihnen sehr dankbar, wenn Sie mich diesbezüglich kontaktieren.

\section{Hardware Entprellung}
Gelegentlich ist es sehr wichtig, eine getaktete, sequenzielle Schaltung schrittweise, manuell über einen Taster zu durchlaufen. Leider erzeugen so ziemlich alle handelsüblichen Taster ein Prellen. Ein solches Prellen führt zu einer undefinierten Abfolge von Signalimpulsen. Da Sie bei CPLDs prinzipiell mit Ihren Flip-Flop-Ressourcen sehr haushalten müssen, wurde für den BitConnector eine Hardwareentprellung vorgesehen. Sofern Ihre Ausführung mit dem 74LVC2G14 IC bestückt ist, ist der Taster SW1 auf dem Board automatisch entprellt. Sollte dies nicht der Fall sein, so können Sie auf Grundlage der nachfolgenden Erläuterungen, eine eigene Hardwareentprellung nachschalten.
\subsection{Prinzip der Hardwareentprellung}
Da die vom Menschen erzeugten Frequenzen der Tastendrücke im Vergleich zum Prellen des Tasters sehr niedrig sind, wurde ein Tiefpassfilter in Form eines RC-Gliedes dem Taster nachgeschaltet. 
Dieser Tiefpass filtert die hochfrequenten Anteile des Prellens aus dem Tastendruck heraus. Das Prellen ist verschwunden. Es entsteht allerdings ein neues Problem. Da ein RC-Glied naturgemäß aus einem Widerstand und einem Kondensator besteht, durchläuft dieser Kondensator eine Ladespannung, die dem natürlichen Logarithmus sehr nahe kommt (siehe beispielsweise \autocite{RC}). Eine digitale Schaltung auf CMOS-Basis benötigt jedoch eine steile Signalflanke, also beispielsweise einen Signalwechsel von 0V auf direkt 3,3V. Andernfalls besteht die Gefahr, dass die Schaltung in einen undefinierten Zustand abrutscht. Auf Transistorebene kann dieser undefinierte Zustand sehr gefährlich sein, da eine Transistorkonstellation, die es theoretisch so nicht geben sollte, plötzlich anfangen kann, den Strom zu leiten. Zudem werden Sie immer noch keinen auswertbaren Tastenimpuls erwarten können. Es ist daher zwingend anzuraten, diese undefinierten Signalzustände in digitalen Schaltungen zu vermeiden. Dies geschieht hier mit Hilfe eines Schmitt-Triggers. Der Schmitt-Trigger soll verkürzt dargestellt, den undefinierten Spannungsbereich auf einen definierten high- oder low- Pegel zurück bringen. Die charakteristische Hysterese eines Schmitt-Triggers ist dafür verantwortlich, den undefinierten Spannungsbereich zu vermeiden. Sie können sich den Schmitt-Trigger in diesem Fall als den „eigentlichen Schalter“ vorstellen, der am Ausgang immer einen steilen Pegel schaltet, während er am Eingang eine Kondenstorkennlinie „sieht“.
%Grafiken (Auch Schaltplan) und Berechnungen einfügen.

\section{Entwicklungsumgebung}

Momentan gibt es noch keine freie \autocite{FSF} Entwicklungsumgebung für Xilinx CPLDs, weswegen leider auf proprietäre Software der Firma Xilinx zurück gegriffen werden muss.
 
Fraglicherweise bietet Xilinx in seiner aktuellen Entwicklungsumgebung „Vivado“ keine Unterstützung für CPLDs an, siehe \autocite[17]{Vivado}. Dennoch ist es möglich, mit der älteren Design Suite „ISE“, Xilinx CPLDs problemlos zu konfigurieren.
Mit einer Registrierung bei Xilinx erhalten Sie eine kostenlose Lizenz, mit derer Sie die ISE-Demo-Version auf eine Webpack-Version \autocite{ISE-Web} freischalten können. Diese Lizenz ist völlig ausreichend, um alle CPLDs der XC9500 Serie zu konfigurieren.

\section{Die JTAG Schnittstelle via 6 Pin IDC-Header}

Für die Übertragung der Konfigurationsdateien auf den CPLD ist ein 6 Pin IDC-Stecker (JTAG Schnittstelle) im 2.54mm Rastermaß vorgesehen. Die 4 aktiven Leitungen zur Datenübertragung sind:

\begin{enumerate}
	\item Pin TCK = Test Clock
	\item Pin TDI = Test Data In
	\item Pin TDO = Test Data Out
	\item Pin TMS = Test Mode Select
\end{enumerate}

\begin{figure}[!h]
	\centering
	
	\caption{Draufsicht JTAG Pin-Header (6 way IDC male connector)}
	\label{fig:pinheader}
\end{figure}

\newpage

Die Abbildung \ref{fig:pinheader} zeigt die Draufsicht dieses Steckers, welcher auf dem Board verlötet ist.
Innerhalb dieser Abbildung erkennen Sie eine „1“, die den ersten Pin markiert. Dieser Pin ist zur Orientierung dem JTAG Test-Takt zugeordnet. Um die Anfertigung eines eigenen Programmierkabels zu erleichtern, wird nachfolgend auch das passende Datenkabel illustriert.

\begin{figure}[!h]
	\centering
	
	\caption{Programmierkabel HW-RIBBON14 zu 6 Pin IDC female}
	\label{fig:data_cable}
\end{figure}

In Abbildung \ref{fig:data_cable} erkennen Sie das favorisierte Datenkabel vom BitConnector zum Programmiergerät. Anders als in Abbildung \ref{fig:pinheader}, ist der 6 Pin Connector diesmal als Buchse ausgeführt und somit gespiegelt. Bei dem HW-RIBBON14 female connector hat sich Xilinx für eine eher exotische Buchse im 2 mm Raster entschieden. Die Kette des Datenkabels sieht abstrakt zusammen gefasst folgendermaßen aus:
\vspace{0.5cm}
\begin{center}
	PC<->USB-Kable<->Programmierer<->Programmierkabel<->BitConnector
\end{center}

\vspace{0.5cm}

Falls Sie kein passendes Kabel zur Hand haben, können Sie die herausgeführten JTAG Pins von den beiden Stiftleisten über ein Steckbrett abgreifen. Die passende Pinbelegung können Sie Kapitel \ref{sec:Pins} entnehmen.
Falls Sie mehrere BitConnectoren auf einer Platine gesockelt haben, bieten sich diese Pins ebenfalls an, um die CPLDs mit nur einer herausgeführten Schnittstelle sequenziell zu konfigurieren.

Für die Ansteuerung der JTAG-Schnittstelle wird ein Programmiergerät benötigt. Dieses gibt es in unterschiedlichen preislichen Ausführungen, wie das standard „Xilinx Platform Cable USB 1/II“, eine kleinere und günstigere Version für Universitäten „XUP USB-JTAG Programming Cable“ oder diverse sehr günstige Nachbauten zum DLC9G oder zum DLC9LP. 

%Die Pins „Global Clock“ und „Global Reset“ sind neben den klassischen I/O Pins Zusatzfunktionen, die erst softwareseitig in der „ISE“ aktiviert werden müssen.

\newpage
\printbibliography
\end{document}

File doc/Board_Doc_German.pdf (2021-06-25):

## Dokumentation des BitConnector v5Xe

Michael Krause
CC BY-SA 4.0
25. Juni 2021

## MiJa 1 Einführung

Die noch immer andauernden Bemühungen der mikrokosmischen Minimierung von integriertern Schaltkreisen hat Integrationsdichten hervorgebracht, die traditionelle Schaltkreise wie einzelne Register, Zähler, ALUs oder Multiplexer vom Markt verschwinden ließen. Aus der Sicht des Endkonsumentenmarktes mag dieser Schritt folgerichtig sein, jedoch gibt es jenseits dessen noch immer das Bedürfnis auf der Register-Transfer Ebene oder darunter, Logikschaltkreise zu modellieren und zu realisieren. Dieses Bedürfnis kann beispielsweise der akademischen Lehre, dem Wunsch nach Parallelisierung oder der Vorgabe zeitkritischer Anwendungen entspringen. Obwohl es diesbezüglich eine Vielzahl von FPGAs und CPLD-Typen zur Abhilfe gibt, gestaltet sich der prototypische Aufbau auf einem Steckbrett mit Hilfe dieser Chips als nahezu unmöglich. Derartige Chips besitzen meist eine Vielzahl an Pins, die nicht im Dual in-line package (DIP) vorliegen. Der BitConnector versucht dieses Problem zu lösen.

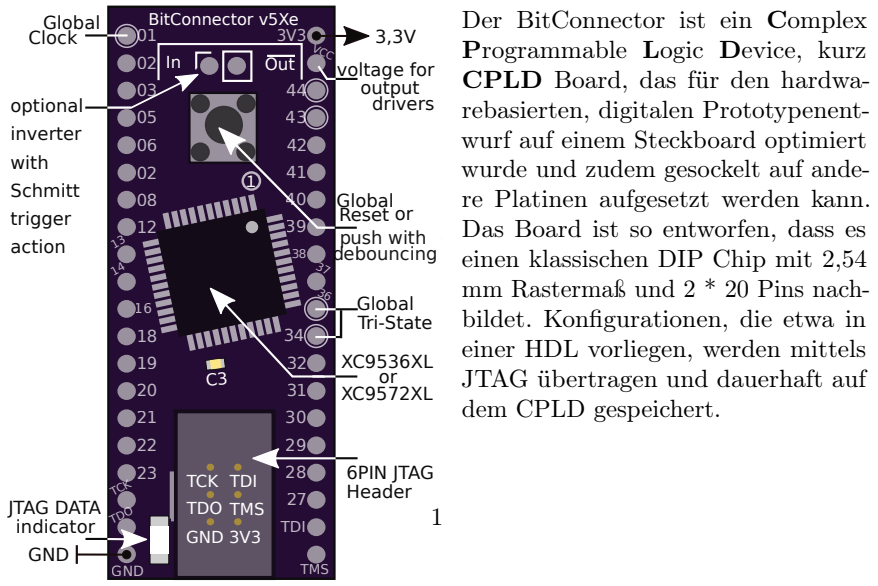
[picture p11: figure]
TCK; TDO; GND; VCC; TDI; TMS; 6PIN JTAG Header TCK TDI TDO TMS; GND 3V3; Global Reset; voltage for output drivers; JTAG DATA indicator; Global; Clock; BitConnector v5Xe; Out; optional inverter with Schmitt trigger action; Global Tri-State; debouncing; push with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

Abbildung 1: BitConnector v5Xe

## 2 Eckdaten

BitConnector Board-Spezifikation
- Anzahl der frei beschaltbaren Ein/Ausgänge: | 33 GPIOs¹ und ein Taster
- Gesamtanzahl der Pins: | 2 Reihen * 20 Pins (2,54mm)
- kompatible CPLD-Varianten: | XC9572XL sowie XC9536XL
- Max. Produktterme: | 1600 bei 72XL/800 bei 36XL
- IC-Package: | VQ44

Absolute, maximale Belastbarkeit:

- Versorgungsspannung bezogen auf GND: | -0,5V bis 4V
- Eingangsspannung bezogen auf GND: | -0,5V bis 5,5V
- Max. Stromfluss bei max. 70 °C Chiptemp.: | ≈ 1, 6A (siehe Kapitel 4.4)

Es wird empfohlen, Spannungen über und unter 3,3V(±0, 3V ) zu vermeiden!

## 3 Pinbelegung BitConnector v5Xe

DIP-links | CPLD Pin | Funktion
1 | 1 | GPIO¹ , GCK3¹
2 | 2 | GPIO¹
3 | 3 | GPIO¹
4 | 5 | GPIO¹
5 | 6 | GPIO¹
6 | 7 | GPIO¹
7 | 8 | GPIO¹
8 | 12 | GPIO¹
9 | 13 | GPIO¹
10 | 14 | GPIO¹
11 | 16 | GPIO¹
12 | 18 | GPIO¹
13 | 19 | GPIO¹
14 | 20 | GPIO¹
15 | 21 | GPIO¹
16 | 22 | GPIO¹
17 | 23 | GPIO¹
18 | 11 | TCK¹ JTAG
19 | 24 | TDO¹ JTAG
20 | 17,25,4 | GND
DIP-rechts | CPLD-Pin | Funktion
1 | 15,35 | 3V3/VINT

1
2 | 26 | VIO

1
3 | 44 | GPIO, GCK2¹
4 | 43 | GPIO¹

, GCK1¹
5 | 42 | GPIO¹
6 | 41 | GPIO¹
7 | 40 | GPIO¹
8 | 39 | GPIO¹
9 | 38 | GPIO¹
10 | 37 | GPIO¹
11 | 36 | GPIO¹

, GTS1¹
12 | 34 | GPIO¹

, GTS2¹
13 | 32 | GPIO¹
14 | 31 | GPIO¹
15 | 30 | GPIO¹
16 | 29 | GPIO¹
17 | 28 | GPIO¹
18 | 27 | GPIO¹
19 | 9 | TDI¹ JTAG
20 | 10 | TMS¹ JTAG
Taster | 33 | GRS, high active mit hardware debouncing, sonst low active

1GPIO=General Purpose In/Output, GRS=Global Reset, GTS=Global Tri-State, GCK=Global Clock, TDI=Test Data In, TDO=Test Data Out, TCK=Test Clk, TMS=Test
Mode Select, VINT=Supply voltage internal logic, VIO=Supply voltage output driver

2

## 4 Strom und Spannungsversorgung

### 4.1 Spannungsversorgnung VccINT

Wie bei traditionellen ICs auch, befindet sich die Betriebsspannung (VccINT) des BitConnectors oben rechts in Bezug zu GND (unten links).

Die Betriebsspannung sollte 3.6V nicht übersteigen und 3V nicht unterschreiten. [1, S. 3]

Es wurde bewusst auf einen Spannungsregler verzichtet, um den zu treibenden Ausgangsstrom nicht zu begrenzen. Diese Entscheidung schafft zwar Flexibilität, verlagert aber die Verantwortung auf eine korrekte Spannungsversorgung auf die externe Peripherie.
An dieser Stelle ist noch erwähnenswert, dass Sie nach [2, S. 17] einen „ stromlosen“ I/O-Pin mit einer maximalen Spannung von VccINT+4V treiben dürfen.

### 4.2 Definition der I/O Spannung über VccIO

Neben der Versorgungsspannung VccINT existiert direkt darunterliegend der Pin VccIO(siehe Kapitel 3), welcher die Höhe der Pin-Ausgangsspannung definiert. Sie können die Spannung der Ausgänge bei einem h-Pegel auf 3,3V oder auf 2,5V setzen. Für eine Ausgangsspannung von 3,3 Volt, sollte VccIO zwischen 3V und 3,6V liegen. Wird dagegen eine Ausgangsspannung von 2,5V forciert, sollte VccIO zwischen 2,3V und 2,7V liegen [1, S. 3]

### 4.3 Ausgangskennlinie eines XC9536XL CPLDs

Sobald Sie einen Pin des BitConnectors mit einem Stromfluss belasten, in dem Sie beispielsweise eine LED ansteuern, sackt die Ausgangsspannung des entsprechenden I/O-Pins ab. Dieser Effekt geht auf den verwendeten CPLD zurück. Um nun eine Vorstellung zu erhalten, wie sich der treibende Strom zur Spannung verhält, hat der Autor einige stichpunktartig Messungen durchgeführt. Diese Messwerte sind in Abbildung 2 mittels Bezierinterpolation grafisch dargestellt. Die Messreihe wurde über ein Fluke 87 III , strom-/spannungsrichtig aufgenommen, VccINT und VccIO betrugen 3,3V, IO33 (CPLD Pin 44) war der (einzige) belastete Ausgang. Obwohl es sich bei der Messung um einen XC9536XL CPLD handelt, ist es naheliegend, dass der XC9572XL eine sehr ähnliche Charakteristik zeigt. Verwunderlich ist, dass die Messreihe teilweise signifikant von der Xilinx-Spezifikation [3, S. 6] abweicht. Dennoch wurde in Kapitel 4.4 auf die von Xilinx veröffentlichte Spezifikation zurück gegriffen.

3

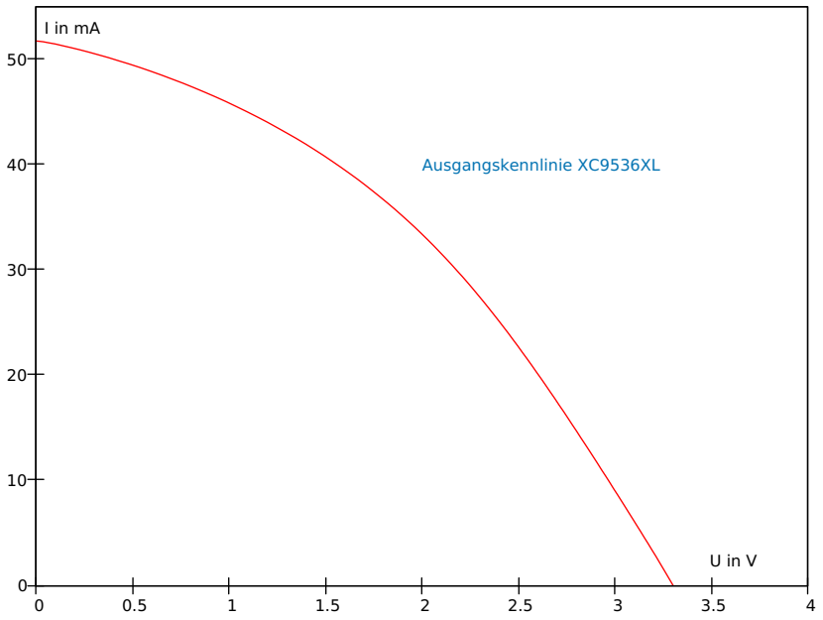
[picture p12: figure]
Ausgangskennlinie XC9536XL

Abbildung 2: Ausgangskennlinie eines XC9536XL

### 4.4 Maximaler Stromfluss Imax

Wer nach einem konkreten Wert bezüglich der maximal zulässigen Stromaufnahme im Datenblatt [1] des XC9572XL oder des XC9536XL sucht, wird keine derartige Angabe finden. Zwar wird eine Abschätzung der zu erwartenden Stromaufnahme über eine Formel angegeben, welche die Frequenz, Anzahl der verwendeter Macrozellen u.s.w. mit einbezieht, jedoch bleibt ein maximal zulässiger Stromfluss Imax unerwähnt. Der Hauptgrund dafür dürfte wohl an der variablen Umgebungstemperatur und in der individuell eingesetzten Kühlung des ICs liegen. Eine plausible Annahme für derartige Werte und die damit einhergehende maximale Stromaufnahme wäre von Xilinx an dieser Stelle jedoch angebracht gewesen und sei es nur, um eine erste Abschätzung zu bekommen.

Um eine solche Abschätzung der maximalen Stromaufnahme Imax soll es nachfolgend gehen. Die Berechnung ist ein wenig müßig und führt über verschiedene Dokumentationen. Zuerst wird die zu Imax zugehörige Verlustleistung Pd über folgende Ungleichung berechnet.[2, S. 16]:

Tjmax < (ΘJC ∗ Pd) + Ta

4

kurze Variablenbeschreibung:

- Tjmax: Maximaltemperatur in °C bezogen auf das IC Package
(70 °C für Kunststoff) [4, S. 54]
- ΘJC : Wärmeflusswiderstand in °C/[W] zwischen der Chipoberfläche und der Oberfläche des Gehäuses [4, S. 53] (8.2 °C/W für 72/36 in VQ44)
- Pd: tatsächliche Leistung in [W]att, welche sich in Hitze äußert [2, S. 16]
- Ta: Umgebungstemperatur in °C (50 °C)

Um ΘJC nicht aufwendig durch eine Messung bestimmen zu müssen, bietet Xilinx eine Datenbank an [5]. Für den XC9572XL/XC9536XL liegt dieser Wert bei 8.2 °C/W im VQ44 Package.

Zudem schlägt Xilinx für Tjmax einen Wert von 70 °C für Kunststoffgehäuse vor. Dieser Wert ist ebenfalls für beide möglichen Chipvarianten angebracht.

Die Umgebungstemperatur des Chips wird vorsichtig mit 50 °C veranschlagt.

Ausgehend von diesen Annahmen berechnet sich die Verlustleistung nach [2,
S. 16] wie folgt:

70°C = (8.2°C/W ∗ Pd) + 50°C ⇒ 20°C = (8.2°C/W ∗ Pd) ⇒
2, 439W = Pd

Weiter ist notwendig, die Verlustleistung in Pd = Pddesign +PdIO aufzuschlüsseln. Pddesign repräsentiert hierbei die Leistung ohne eine Last, also die Leistung die der Chip selbst für sich beansprucht, ohne einen Ausgang zu treiben. Dieser Wert sollte gemessen werden und lautet für den BitConnector rund 40mW. Wird dieser Wert aus Sicherheitsgründen verdoppelt, ist von rund 80mW auszugehen.

Somit gilt:

2, 439W = 80mW + PdIO

Um schlussendlich auf den gesuchten Wert Imax zu kommen, wird folgende Formel nach [2, S. 16] herangezogen:

Imax ∗ (V CC − 1, 85V ) = Pd − Pddesign

Sicher fragen Sie sich, woher die 1,85V herstammen. Dieser Wert wurde über die Kennlinienfelder in [3, S. 6] abgelesen und sagt aus, dass bei einem Stromfluss von 30mA, die Spannung des entsprechenden Ausgangs auf 1,85V absinkt. Daraus folgt:

5

Imax ∗ (3, 3V − 1, 85V ) = 2, 439W − 0.08W → Imax ≈ 1, 63A

Der Wert Imax sagt aus, dass bei einer I/O-Spannung von 1,85V und einer Stromstärke von 30mA pro Ausgang, eine Gesamtstromstärke von 1,63A erreicht wird. Hierbei liegt die Chiptemperatur ≤ der als kritisch angenommenen 70°C. Auffällig ist, dass die 1,63A in dieser Konstellation im Bitconnector nie erreicht werden können, da dieser nur 34 mögliche Ausgänge bietet. Mit den getroffenen Annahmen ist jedoch die Versorgung von 1,63A
0,03 ≈ 54 Ausgänge möglich.

Bitte verlassen Sie sich nicht auf die angegebene Berechnung und überprüfen Sie auch die Quellen. Sollten Sie einen Fehler finden, wäre ich Ihnen sehr dankbar, wenn Sie mich diesbezüglich kontaktieren.

## 5 Hardware Entprellung

Gelegentlich ist es sehr hilfreich, eine getaktete, sequenzielle Schaltung schrittweise über das Drücken eines Taster zu durchlaufen. Leider erzeugen so ziemlich alle handelsüblichen Taster ein sogenanntes „Prellen“, da die Kontakte des Tasters nicht sauber schließen oder öffnen. Ein solches Prellen führt zu einer unvorhersagbaren Abfolge von Signalimpulsen. Schauen Sie sich hierfür einmal die Abbildung 3 genauer an.

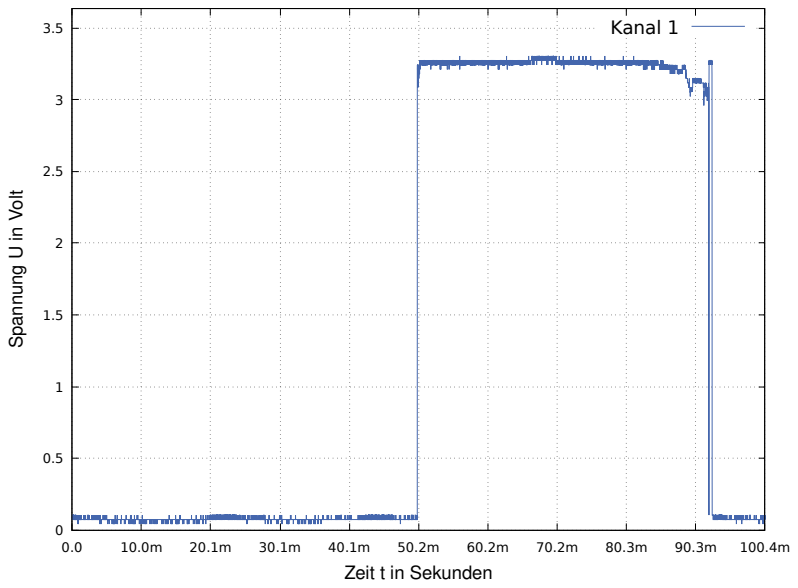
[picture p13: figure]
Spannung U in Volt; Zeit t in Sekunden; Kanal 1

Abbildung 3: Tastendruck am BitConnector ohne Entprellung

6

Hier wird ein einfacher Tastendruck über ein Oszillogramm grafisch veranschaulicht. Interessant ist der Bereich der fallende Flanke ab 80 Millisekunden, also ungefähr an der Stelle, an dem der Taster wieder losgelassen wird. Wenn Sie diesen Bereich kritisch betrachten, werden Sie bemerken, dass es bei ungefähr 92 Millisekunden bereits einen ungewollten Wechsel der Signalflanke gibt. Lassen Sie uns diesen Bereich mit der „Lupe“ in Abbildung 4 etwas näher betrachten.

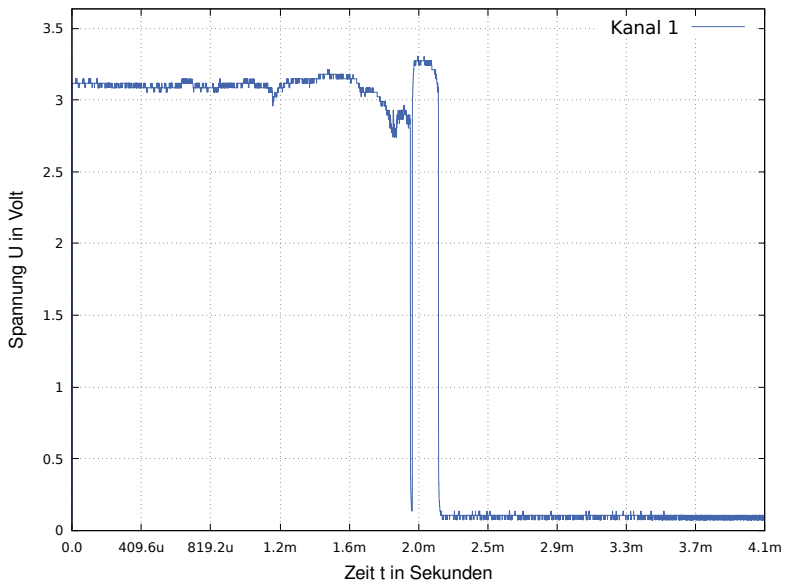
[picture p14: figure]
Spannung U in Volt; Zeit t in Sekunden; Kanal 1

Abbildung 4: Nahaufnahme der fallenden Flanke aus Abbildung 3

Sie erkennen deutlich, dass der Signalpegel in Abbildung 4 bereits bei ungefähr 2 Millisekunden hin und herspringt und somit mehrere Flanken erzeugt. Diese Signalflanken sind gerade bei sequenziellen Schaltungen, die auf fallende oder steigende Flanken reagieren problematisch. Eine einfache Zählerschaltung, die mit jedem Tastendruck „1“ hinzu addiert, wird augenscheinlich nicht funktionieren. So scheint es, als würde der Zähler einzelne Zählschritte beim Drücken oder beim Loslassen des Tasters überspringen. Mit einem höherwertigen Oszilloskop ließe sich der problematische Bereich noch näher untersuchen, was weitere Taktwechsel und somit weitere Zählimpulse mit nur einem Tastendruck aufdecken könnte. Da Sie bei CPLDs prinzipiell mit Ihren Flip-Flop-Ressourcen sehr haushalten müssen und keinen Mikrocontroller für eine Entprellroutine haben, wurde für den BitConnector eine Hardwareentprellung vorgesehen.

7

Sollte Ihr BitConnector mit dem 74LVC2G14 IC bestückt sein, so ist auch der Taster SW1 automatisch entprellt. Ein Tastendruck sollte dann wie in Abbildung 5 eine einzige und saubere Flanke erzeugen.

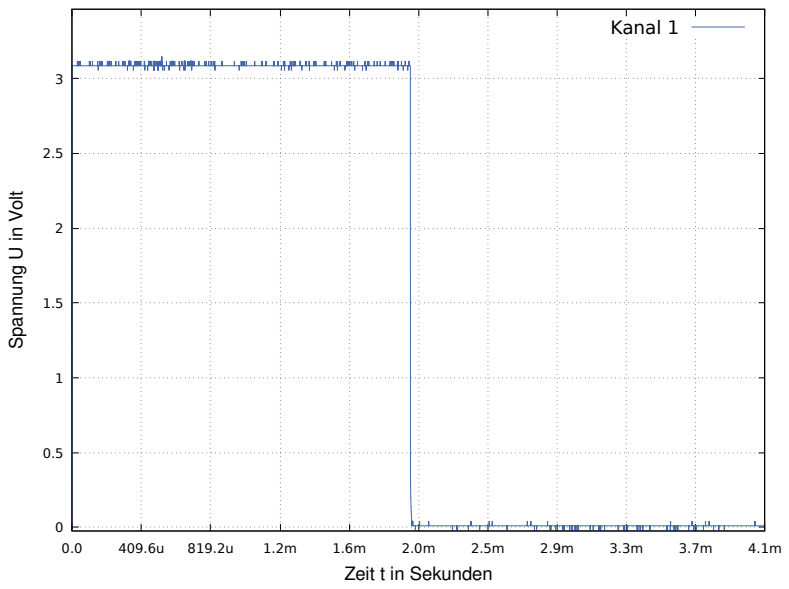
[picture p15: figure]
Spannung U in Volt; Zeit t in Sekunden; Kanal 1

Abbildung 5: Tastendruck am BitConnector mit Hardware-Entprellung

Sollte dies nicht der Fall sein, so können Sie auf Grundlage der nachfolgenden Erläuterungen eine eigene Hardwareentprellung nachschalten.

### 5.1 Prinzip der Hardwareentprellung

Da die vom Menschen erzeugten Frequenzen der Tastendrücke im Vergleich zum Prellen des Tasters sehr niedrig sind, ist es naheliegend einen Tiefpassfilter in Form eines RC-Gliedes dem Taster vorzuschalten. Dieser Tiefpass filtert die hochfrequenten Anteile des Prellens aus dem Tastendruck heraus. Das Prellen ist verschwunden. Es entsteht allerdings ein neues Problem. Da ein RC-Glied naturgemäß aus einem Widerstand und einem Kondensator besteht, durchläuft dieser Kondensator eine Ladespannung, die dem natürlichen Logarithmus sehr nahe kommt [6]. Eine digitale Schaltung auf CMOS-Basis benötigt jedoch eine steile Signalflanke, also beispielsweise einen Signalwechsel von 0V auf direkt 3,3V. Andernfalls besteht die Gefahr, dass die Schaltung eine gewisse Zeit einen undefinierten Zustand annimmt. Auf Transistorebene kann dieser undefinierte Zustand gefährlich sein, da eine Transistorkonstellation, die es theoretisch so nicht geben sollte, plötzlich anfangen kann, den Strom zu leiten. Zudem werden Sie immer noch keine Freude beim auswerten des Tastenimpuls haben. Es ist

8

daher nachdrücklich anzuraten, diese undefinierten Signalzustände in digitalen Schaltungen zu vermeiden. Dies geschieht hier mit Hilfe eines Schmitt-Triggers. Der Schmitt-Trigger soll verkürzt dargestellt, den undefinierten Spannungsbereich vor dem digitalen Eingang einer Schaltung über eine sogenannte „charakteristische Hysterese“ vermeiden. Sie können sich den Schmitt-Trigger in diesem Fall als den „eigentlichen Schalter“ vorstellen, der an seinem Ausgang immer einen steilen Pegel schaltet, während er am Eingang eine Kondenstorkennlinie „sieht“.

## 6 Entwicklungsumgebung

Momentan gibt es noch keine vollumfängliche und freie [7] Entwicklungsumgebung für Xilinx CPLDs, weswegen der Autor auf proprietäre Software der Firma Xilinx zurückgreifen muss. Fraglicherweise bietet Xilinx in seiner aktuellen Entwicklungsumgebung „Vivado“ keine Unterstützung für CPLDs an, siehe [8,
S. 17]. Dennoch ist es möglich, mit der älteren Design Suite „ISE“, Xilinx CPLDs problemlos zu konfigurieren. Mit einer Registrierung bei Xilinx erhalten Sie eine kostenlose Lizenz, mit derer Sie die ISE-Demo-Version auf eine Webpack-Version
[9] freischalten können. Diese Lizenz ist ausreichend, um alle CPLDs der XC9500 Serie ohne Einschränkungen zu konfigurieren.

## 7 Die JTAG Schnittstelle via 6 Pin IDC-Header

Für die Übertragung der HDL Konfigurationsdateien auf den BitConnector ist ein 6 Pin IDC-Stecker (JTAG Schnittstelle) im 2.54mm Rastermaß vorgesehen. Die 4 aktiven JTAG-Leitungen zur Datenübertragung sind:

1. Pin TCK = Test Clock
2. Pin TDI = Test Data In
3. Pin TDO = Test Data Out
4. Pin TMS = Test Mode Select

3V3

### GND

### TDI TMS

### TCK TDO

1

Abbildung 6: Draufsicht JTAG Pin-Header (6 way IDC male connector)

9

Die Abbildung 6 zeigt die Draufsicht dieses Steckers, welcher auf dem Board verlötet ist. Innerhalb dieser Abbildung erkennen Sie eine „1“, die den ersten Pin markiert. Dieser Pin ist zur Orientierung dem JTAG Test-Takt zugeordnet. Um die Anfertigung eines eigenen Programmierkabels zu erleichtern, wird nachfolgend auch das passende Datenkabel illustriert. Ich möchte Sie ermutigen, die Anfertigung eines eigenen Kabels nicht zu fürchten. Die Minimalausrüstung sehen sie in Abbildung 7


Abbildung 7: Werkzeug und Ribbon Cable + IDC-Stecker zum selber crimpen

Da es mehrere Programmiergerät gibt, existieren somit mehrere Stecker-Möglichkeiten und Adapter. In Abbildung 8 erkennen Sie ein mögliches Datenkabel vom Bit-Connector zum Programmiergerät. Anders als in Abbildung 6, ist der 6 Pin Connector diesmal als Buchse ausgeführt und somit gespiegelt.
Bei dem HW-RIBBON14 female connector hat sich Xilinx für eine eher exotische Buchse entschieden. Die Kette des Datenkabels sieht abstrakt zusammen gefasst folgendermaßen aus:

PC<->USB-Kable<->Programmierer<->Programmierkabel<->BitConnector

10

Abbildung 8: Programmierkabel HW-RIBBON14 zu 6 Pin IDC female

Falls Sie kein passendes Kabel zur Hand haben, können Sie die herausgeführten JTAG Pins von den beiden Stiftleisten über ein Steckbrett abgreifen(rote Markierung).


Abbildung 9: Die JTAG Schnittstelle, einmal rot umkreist als Stiftleisten und grün umkreist als IDC Header ausgeführt

Sofern Sie mehrere BitConnectoren auf einer Platine gesockelt haben, bieten sich die Pins der Stiftleisten ebenfalls an, um die CPLDs mit nur einer herausgeführten Schnittstelle sequenziell zu konfigurieren.

### 7.1 JTAG Programmiergerät

Für die Ansteuerung der JTAG-Schnittstelle wird ein Programmiergerät benötigt. Hier gibt es mehrere Lösungen mit unterschiedlichen Funktionsumfang. Verbreitet sind 4 Versionen des Xilinx Platform Cable USB I/II. Dabei entfallen bereits 3 Versionen auf das Platform Cable I:

- DLC9G (neuste Version bezüglich Platform Cable I)
- DLC9LP (Vorgänger des DLC9G)
- DLC9 (älteste Version)

11

Zu diesen 3 Versionen schreibt Xilinx u.a.: „The DLC9G and legacy DLC9LP cable models draw less than 100 mA from the host USB port. The legacy DLC9 cable model requires 230 mA to operate in USB 2.0 Hi-Speed mode or 150 mA to operate in USB 2.0/1.1 full-speed mode.“ [10, S. 2]

Das Xilinx Platform Cable USB II wird momentan unter der Versionsbezeichnung „DLC10“ gehandelt. Die hohen Verbreitung dieser Programmiergeräte hat dazu beigetragen, dass es selbige auch als preisgünstige Nachbauten von anderen Herstellern zu einem Zehntel des Preises gibt.


Abbildung 10: oben: XUP USB-JTAG Programming Cable
unten: Platform Cable USB II DLC10

Als Alternative zum „Platform Cable I/II“ existiert eine kleine und günstigere Variante aus dem „Xilinx University Program“ dass die Bezeichnung „XUP USB-JTAG Programming Cable“ trägt. Sie können es nachfolgend in Abbildung 10 erkennen. Allerdings scheint diese Variante mit dem heutigen Preisverfall des Platform Cables I/II wenig attraktiv zu sein. Der Vollständigkeit halber soll an dieser Stelle noch das DLC7/Parallel Cable IV erwähnt werden, dass jedoch in der neuen Entwicklungsumgebung von Xilinx/Vivado nicht mehr unterstützt wird
[11] und aufgrund der „ausgestorbenen“ parallelen Schnittstelle bei Anwendern ebenfalls nur mehr selten anzutreffen sein dürfte. Wenn Sie keinen Wert auf Zusatzfunktionen wie „SPI PROM Support, ChipScope oder AES-Cryptographic“ legen, sollte die Wahl des Programmers eine untergeordnete Rolle spielen.

12

### 7.2 Offene JTAG Hardware-/Softwarelösungen für Xilinx

Es gibt einige Projekte, die sich darum bemühen, alternative und offene JTAG Hardware-/Softwarelösungen für Xlinix Produkte anzubieten. Um ein CPLD/FPGA zu konfigurieren, wird ein Mikrocontroller (JTAG-Programmiergerät) benötigt, der den JTAG Standard „IEEE 1149.1“ und eventuelle herstellerspezifische Abweichungen implementiert. Um mit diesem Mikrocontroller kommunizieren zu können, wird weiter eine PC-Software (JTAG Client) benötigt, welche die HDL synthetisierte Konfiguration (im XSVF Format) an diesen Mikrocontroller überträgt. Der Mikrocontroller nimmt letztlich über das vom PC aus übertragene XSVF Format die Konfiguration des CPLD/FPGA mittels JTAG vor.

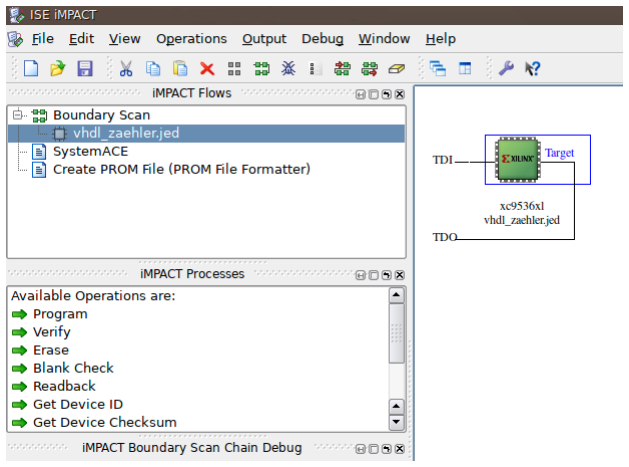
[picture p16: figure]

Abbildung 11: Das proprietäre iMPACT überträgt und verifiziert die HDL Konfiguration (über ein JTAG Programmiergerät) auf dem CPLD oder FPGE

Um aber auf die offenen Alternativen hinzuweisen, soll hier die Lib(X)SVF von Clifford Wolf[12] Erwähnung finden. Lib(X)SVF ist eine C-Bibliothek zur Implementierung/Umsetzung von JTAG-Programmiergeräten mittels XSVF/SVF Format. Eine konkrete Implementierung ist beispielsweise das „clujtag“ Projekt, wobei clujtag [13] die Firmware eines einfachen AVR basierten Programmiergeräts bildet und clujtag-client [14] eine kommandozeilenbasierte Alternative zu Xilnix iMPACT darstellt. In welchen Umfang diese und andere Projekte heute tragfähig sind, kann der Autor bisher nicht einschätzen.

13

## Literatur

[1] XC9572XL High Performance CPLD - Product Specification. DS057. v2.0. Xilinx. Apr. 2007.
[2] CPLD I/O User Guide. UG445. v1.2. Xilinx. Jan. 2014.
[3] I/V Curves for Xilinx FPGA and CPLD Families. 1-800-255-7778. v1.1. Xilinx. Mai 2001.
[4] Device Package User Guide. UG112. v3.7. Xilinx. Sep. 2012.
[5] Package Thermal Data Query. https : / / www . xilinx . com / cgi - bin / thermal/thermal.pl. (https://www.xilinx.com/cgi-bin/thermal/thermal.pl) accessed: 14-04-2021.
[6] Natürlicher Logarithmus für die Kondensatoraufladung. https : / / et -tutorials.de/5703/naturlicher-logarithmus-fur-die-kondensatoraufladung/. (https://et-tutorials.de/5703/naturlicher-logarithmus-fur-die-kondensatoraufladung/) accessed: 14-04-2021.
[7] Freie Software. Was ist das? https://www.gnu.org/philosophy/freesw.de.html. (https://www.gnu.org/philosophy/free-sw.de.html) accessed: 14-04-2021.
[8] Vivado Design Suite UserGuide - Release Notes, Installation, and Licensing. UG973. v2018.3. Xilinx. Dez. 2018.
[9] Download ISE WebPACK Design Software. https://www.xilinx.com/products/design- tools/ise- design- suite/ise- webpack.html. (https://www.xilinx.com/products/design-tools/ise-design-suite/ise-webpack.html) accessed: 14-04-2021.
[10] Platform Cable USB. DS300. v3.2. Xilinx. Mai 2008.
[11] Parallel Cable IV/Vivado. https://www.xilinx.com/support/answers/54136.html. (https://www.xilinx.com/support/answers/54136.html) accessed: 14-04-2021.
[12] Clifford Wolf. Lib(X)SVF: A library for implementing SVF and XSVF JTAG players. http : / / www . clifford . at / libxsvf/. (http://www.clifford.at/libxsvf/) accessed: 14-04-2021.
[13] Alexey Avdyukhin. Very simple JTAG programmer based on AVR microcontroller with hardware USB. https://github.com/ClusterM/clujtagavr. (https://github.com/ClusterM/clujtag-avr) accessed: 14-04-2021.
[14] Alexey Avdyukhin. Client for AVR-based JTAG programmer. https://github.com/ClusterM/clujtag-client. accessed: 14-04-2021.

14

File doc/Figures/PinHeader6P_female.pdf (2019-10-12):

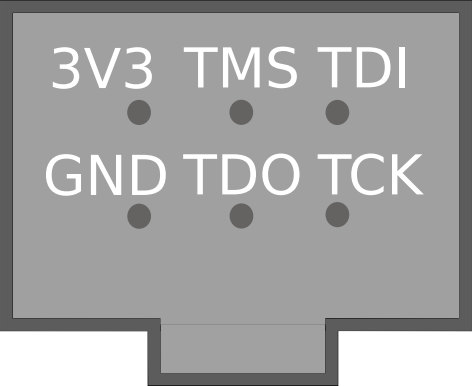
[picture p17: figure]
GND; TMS TDI; TCKTDO

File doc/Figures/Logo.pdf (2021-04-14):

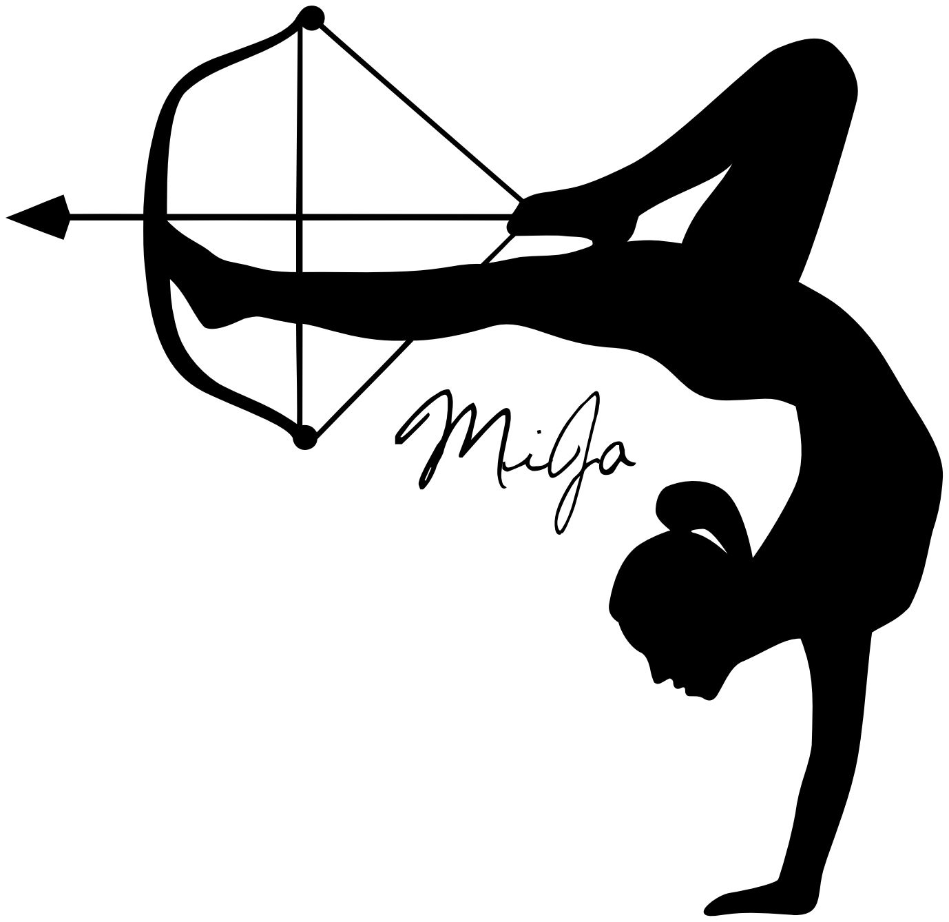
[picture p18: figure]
MiJa

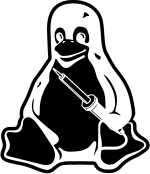
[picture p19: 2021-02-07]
doc/Figures/tux.png

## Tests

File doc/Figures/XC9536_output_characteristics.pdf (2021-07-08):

50

I in mA

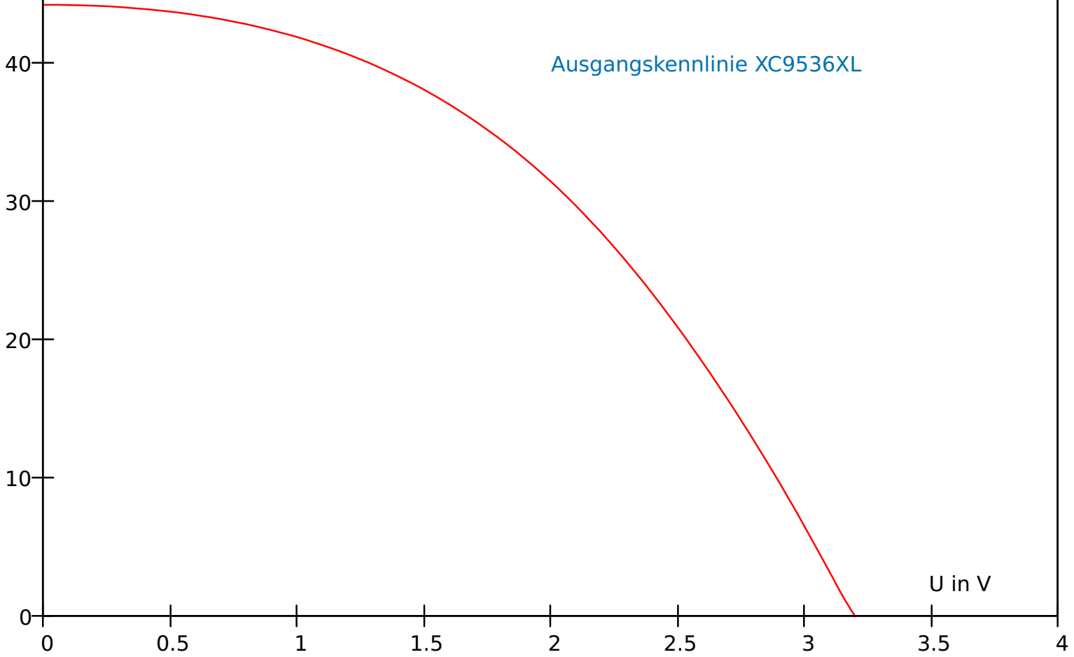
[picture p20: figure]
Ausgangskennlinie XC9536XL

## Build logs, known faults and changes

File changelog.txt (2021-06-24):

BitConnector v5Xe:
	- Optimize the distance between the two pin headers
	- Optimize the placement of the CPLD by 2 degrees to the left
	- As a result of the rotation, all data lines now have at least one width of 10 mils (0.254 mm).
	- Further grounding surfaces were introduced on the top
	- Turn decoupling capacitors to bring them closer to VCC
	- PCB pin label now contains the CPLD pins

BitConnector v5X:
	- switch solder pad for resistors from 1.15mm to 1.20mm
	- add additional 10nF bypass capacitor according to 
	  Xilinx XAPP104 (3.0.1) specification
	- Completely new board layout created to improve 
	  GND and Vcc connection and suppress interference signals
	- fallback to v3X (minimal configuration) is retained 
	- 74LVC2G14 (schmitt trigger) now has a better footprint
	- change logo to tux from ti-band
	
BitConnector v4X:
	- Add hardware debouncing via schmitt trigger action via 74LVC2G14
	- A low-pass filter in front of the schmitt trigger is provided.
	- The schmnitt trigger adds another external inverter. Usable over J2.
 	- As an alternative, add jumper to bridge the schmitt trigger IC 74LVC2G14.
          Use this to fallback to v3X. (Push Button is now active low)
 	- Partial redesign of the routing
	- Move copper logo to the silkscreen on the back

BitConnector v3X:
	- optimize DIP pin spacing for use on a breadboard
	- change JTAG IDC pin header from 8 to 6 pins
	- optimize some circuit paths
	- change logo on copper print

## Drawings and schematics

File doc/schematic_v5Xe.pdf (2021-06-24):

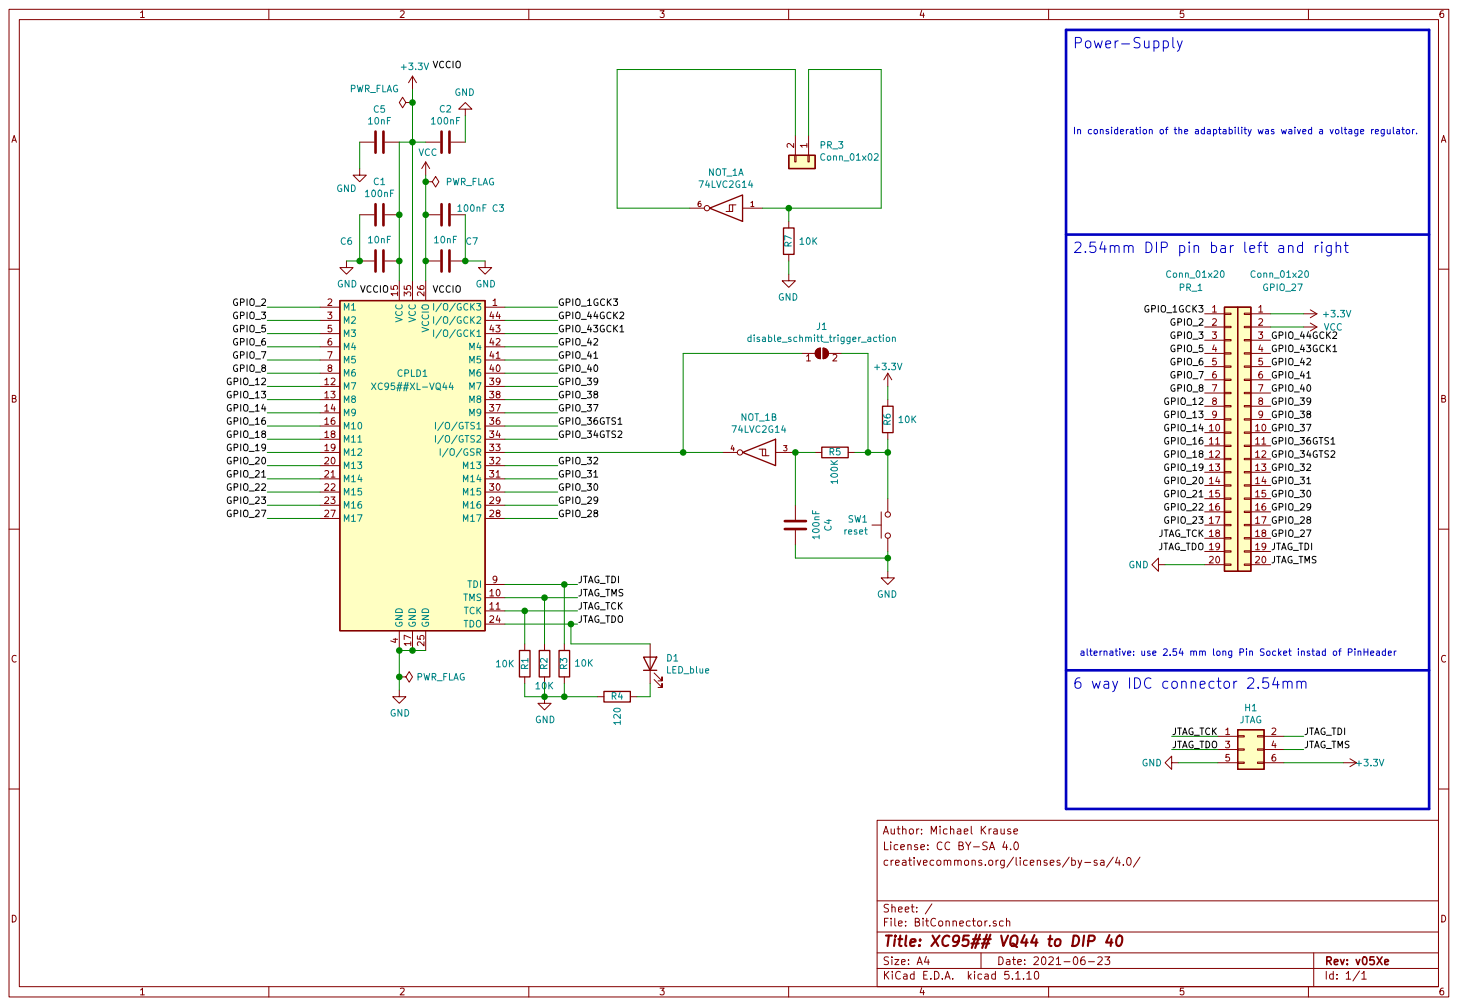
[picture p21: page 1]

In consideration of the adaptability was waived a voltage regulator.

2.54mm DIP pin bar left and right
9 PR_1 Conn_01x20

alternative: use 2.54 mm long Pin Socket instad of PinHeader
6 way IDC connector 2.54mm

File: BitConnector.sch Sheet: / creativecommons.org/licenses/by-sa/4.0/ License: CC BY-SA 4.0 Author: Michael Krause GND

Id: 1/1 Title: XC95## VQ44 to DIP 40

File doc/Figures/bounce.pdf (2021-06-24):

## Kanal 1

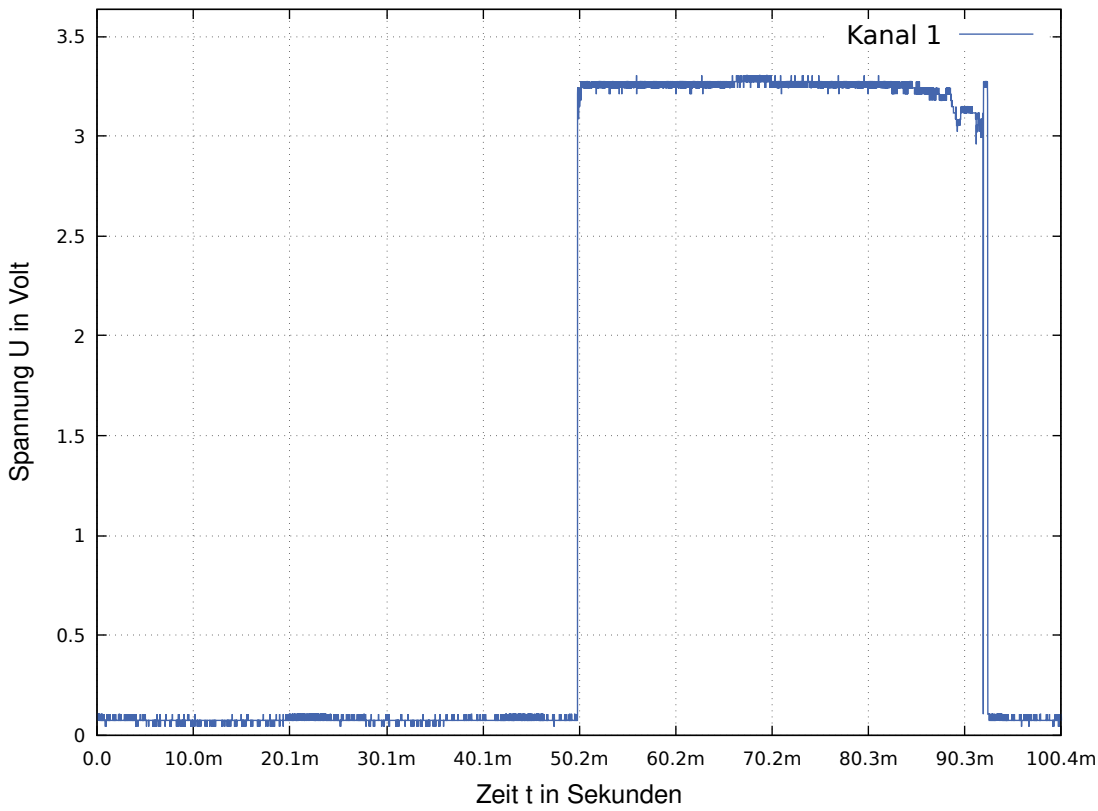
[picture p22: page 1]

Spannung U in Volt

Zeit t in Sekunden

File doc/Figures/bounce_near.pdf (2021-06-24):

## Kanal 1

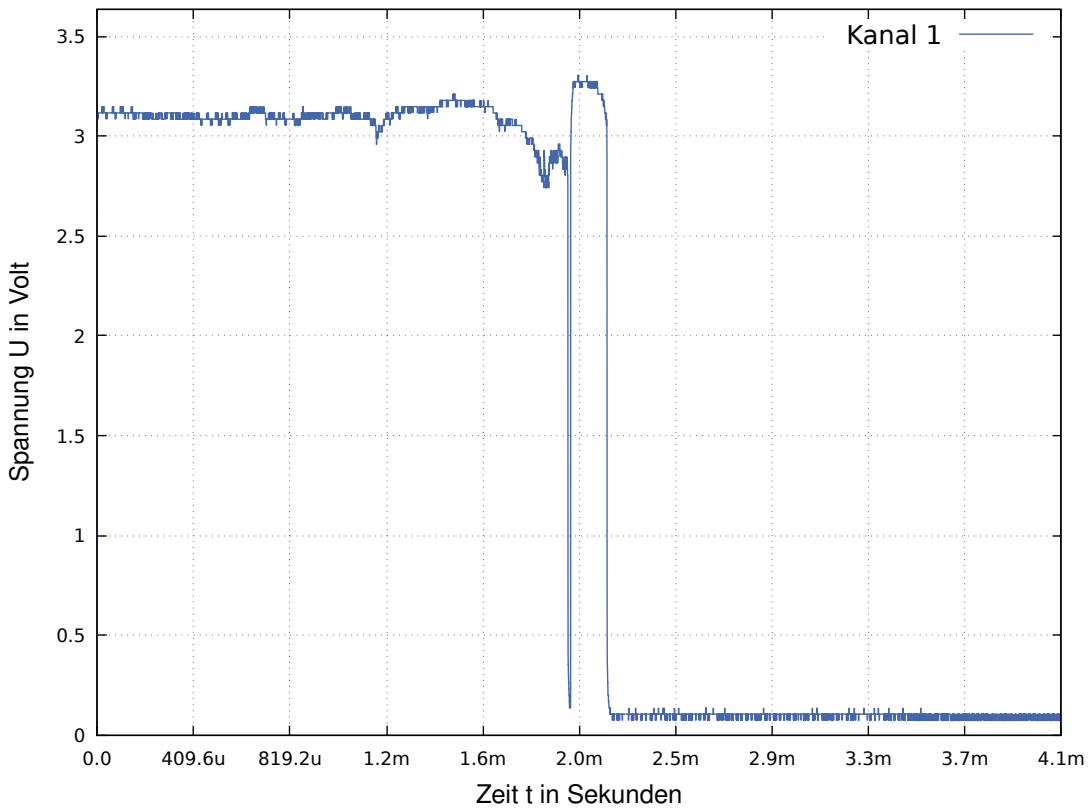
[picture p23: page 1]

Spannung U in Volt

Zeit t in Sekunden

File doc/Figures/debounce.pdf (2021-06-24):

## Kanal 1

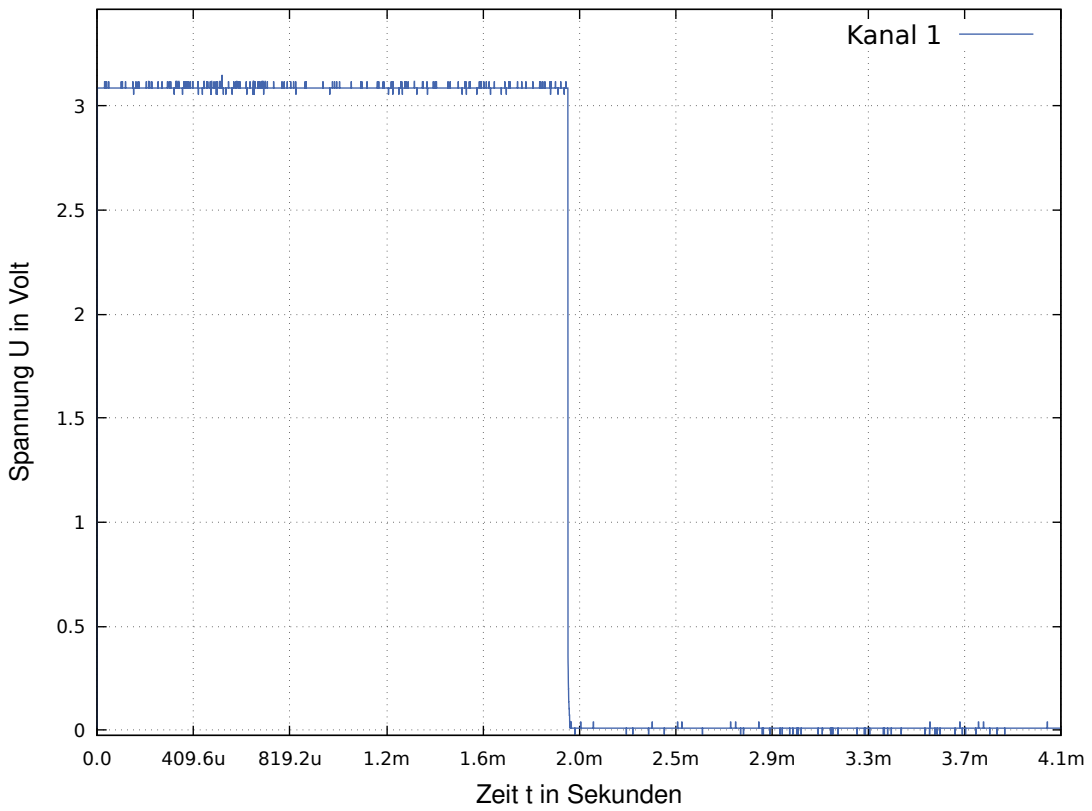
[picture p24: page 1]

Spannung U in Volt

Zeit t in Sekunden

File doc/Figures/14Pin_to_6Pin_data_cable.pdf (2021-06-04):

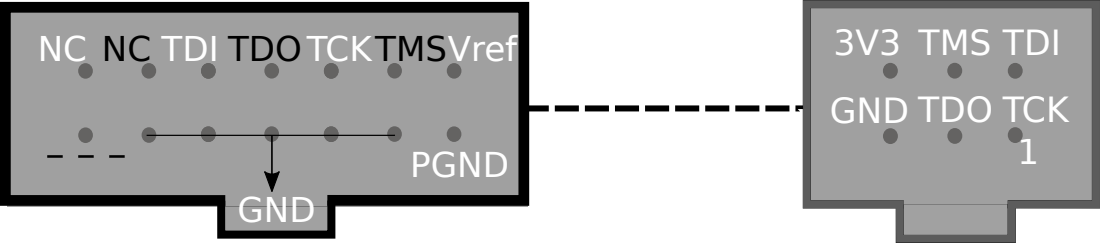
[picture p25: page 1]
NC NC TDI TDOTCKTMSVref; GND; TMS TDI; TCKTDO 1; PGND

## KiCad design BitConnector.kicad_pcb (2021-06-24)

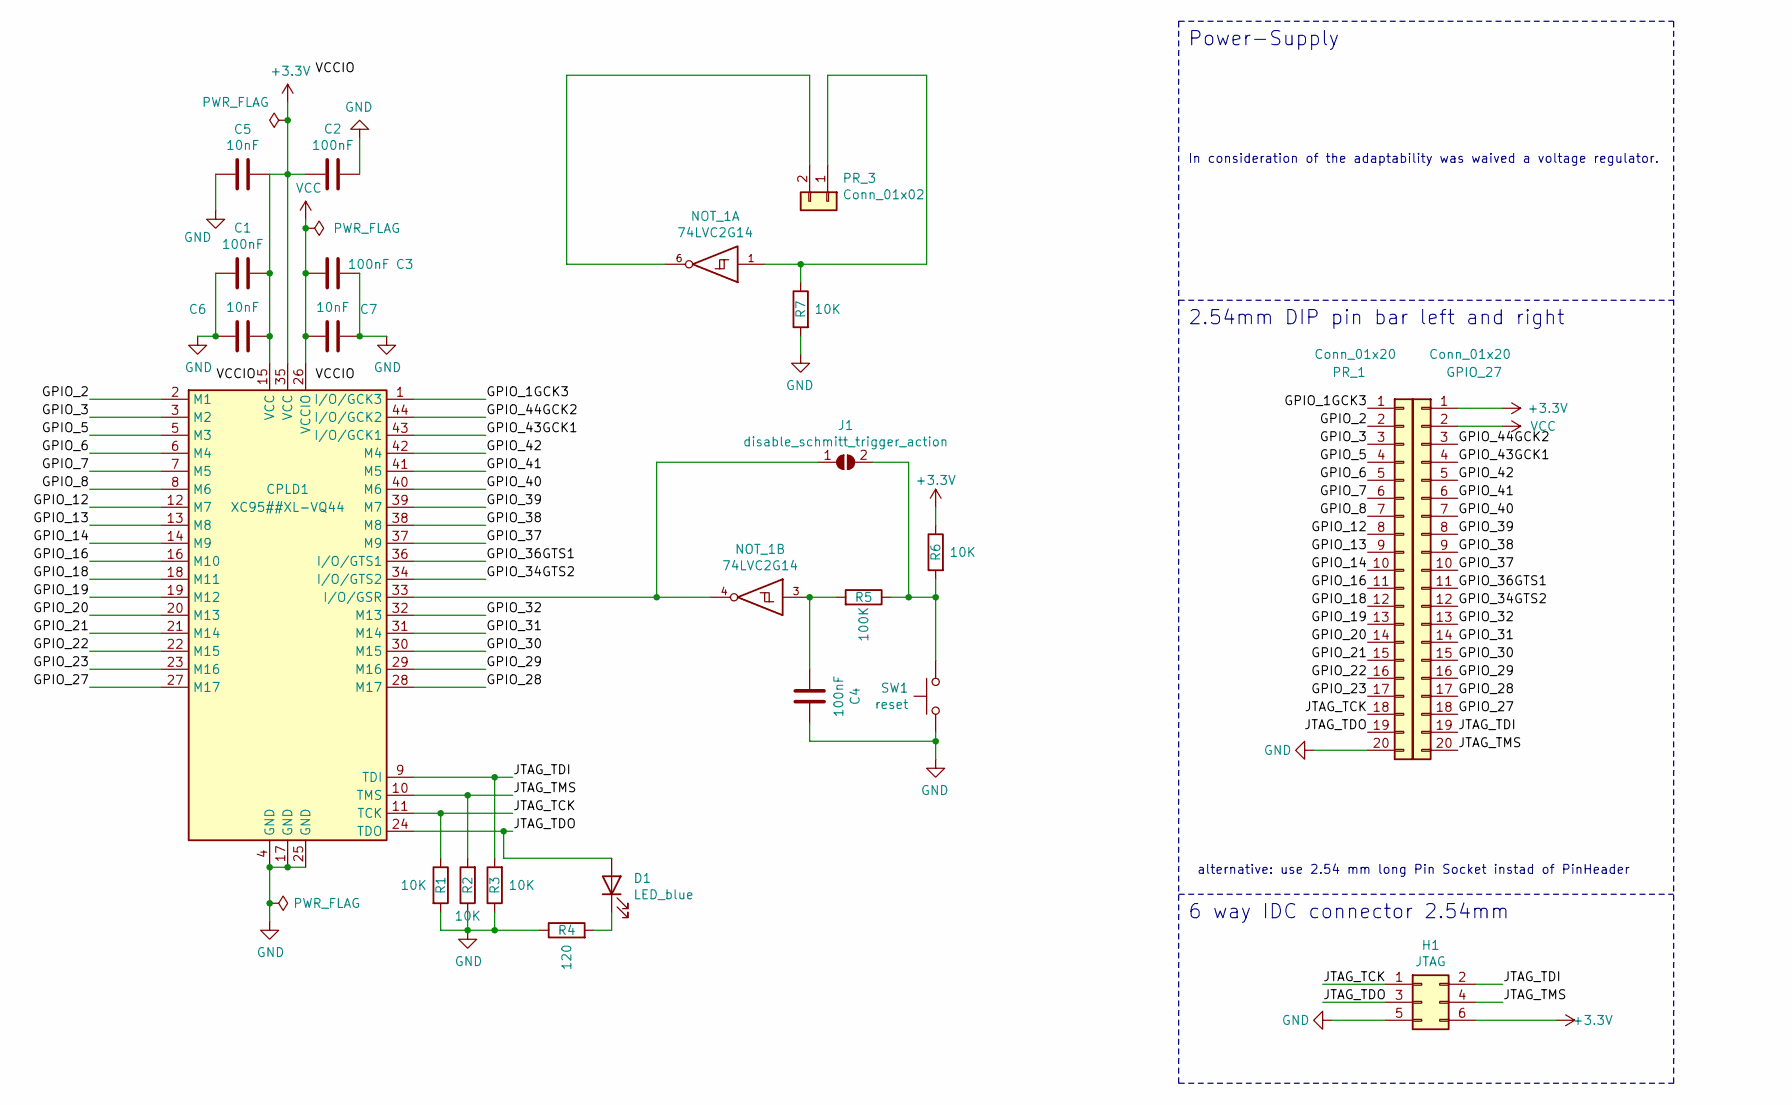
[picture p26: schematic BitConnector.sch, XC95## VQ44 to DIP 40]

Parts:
C1, C2, C3, C4: 100nF; C_0603_1608Metric
C5, C6, C7: 10nF; C_0603_1608Metric
CPLD1: XC95##XL-VQ44; LQFP-44_10x10mm_P0.8mm
D1: LED_blue; LED_1206_3216Metric_Castellated
GPIO_27: Conn_01x20; PinHeader_1x20_P2.54mm_Vertical
H1: JTAG; IDC-Header_2x03_P2.54mm_Vertical
J1: disable_schmitt_trigger_action; SolderJumper-2_P1.3mm_Open_RoundedPad1.0x1.5mm
NOT_1: 74LVC2G14; SC-74-6_1.5x2.9mm_P0.95mm
PR_1: Conn_01x20; PinHeader_1x20_P2.54mm_Vertical
PR_3: Conn_01x02; PinSocket_1x02_P2.54mm_Vertical
R1, R2, R3, R6, R7: 10K; R_0805_2012Metric_Pad1.20x1.40mm_HandSolder
R4: 120; R_0805_2012Metric_Pad1.20x1.40mm_HandSolder
R5: 100K; R_0805_2012Metric_Pad1.20x1.40mm_HandSolder
SW1: reset; SW_PUSH_6mm

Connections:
+3V3: C1.1, C2.2, C5.1, C6.1, CPLD1.15 (VCC), CPLD1.35 (VCC), GPIO_27.1, H1.6, R6.1
/GPIO_1GCK3: CPLD1.1 (I/O/GCK3), PR_1.1
/GPIO_2: CPLD1.2 (M1), PR_1.2
/GPIO_3: CPLD1.3 (M2), PR_1.3
/GPIO_5: CPLD1.5 (M3), PR_1.4
/GPIO_6: CPLD1.6 (M4), PR_1.5
/GPIO_7: CPLD1.7 (M5), PR_1.6
/GPIO_8: CPLD1.8 (M6), PR_1.7
/GPIO_12: CPLD1.12 (M7), PR_1.8
/GPIO_13: CPLD1.13 (M8), PR_1.9
/GPIO_14: CPLD1.14 (M9), PR_1.10
/GPIO_16: CPLD1.16 (M10), PR_1.11
/GPIO_18: CPLD1.18 (M11), PR_1.12
/GPIO_19: CPLD1.19 (M12), PR_1.13
/GPIO_20: CPLD1.20 (M13), PR_1.14
/GPIO_21: CPLD1.21 (M14), PR_1.15
/GPIO_22: CPLD1.22 (M15), PR_1.16
/GPIO_23: CPLD1.23 (M16), PR_1.17
/GPIO_27: CPLD1.27 (M17), GPIO_27.18
/GPIO_28: CPLD1.28 (M17), GPIO_27.17
/GPIO_29: CPLD1.29 (M16), GPIO_27.16
/GPIO_30: CPLD1.30 (M15), GPIO_27.15
/GPIO_31: CPLD1.31 (M14), GPIO_27.14
/GPIO_32: CPLD1.32 (M13), GPIO_27.13
/GPIO_34GTS2: CPLD1.34 (I/O/GTS2), GPIO_27.12
/GPIO_36GTS1: CPLD1.36 (I/O/GTS1), GPIO_27.11
/GPIO_37: CPLD1.37 (M9), GPIO_27.10
/GPIO_38: CPLD1.38 (M8), GPIO_27.9
/GPIO_39: CPLD1.39 (M7), GPIO_27.8
/GPIO_40: CPLD1.40 (M6), GPIO_27.7
/GPIO_41: CPLD1.41 (M5), GPIO_27.6
/GPIO_42: CPLD1.42 (M4), GPIO_27.5
/GPIO_43GCK1: CPLD1.43 (I/O/GCK1), GPIO_27.4
/GPIO_44GCK2: CPLD1.44 (I/O/GCK2), GPIO_27.3
/JTAG_TCK: CPLD1.11 (TCK), H1.1, PR_1.18, R1.1
/JTAG_TDI: CPLD1.9 (TDI), GPIO_27.19, H1.2, R3.2
/JTAG_TDO: CPLD1.24 (TDO), D1.2 (A), H1.3, PR_1.19
/JTAG_TMS: CPLD1.10 (TMS), GPIO_27.20, H1.4, R2.2
GND: C1.2, C2.1, C3.1, C4.2, C5.2, C6.2, C7.1, CPLD1.4 (GND), CPLD1.17 (GND), CPLD1.25 (GND), H1.5, PR_1.20, R1.2, R2.1, R3.1, R4.1, R7.2, SW1.2; also elsewhere on the board
unnamed 39: C4.1, NOT_1.3, R5.2; also elsewhere on the board
unnamed 40: CPLD1.33 (I/O/GSR), J1.1 (A), NOT_1.4; also elsewhere on the board
unnamed: D1.1 (K), R4.2
unnamed: J1.2 (B), R5.1, R6.2, SW1.1
unnamed 43: NOT_1.1, PR_3.1, R7.1; also elsewhere on the board
unnamed 44: NOT_1.6, PR_3.2; also elsewhere on the board
VCC: C3.2, C7.2, CPLD1.26 (VCCIO), GPIO_27.2; also elsewhere on the board

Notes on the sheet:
6 way IDC connector 2.54mm
2.54mm DIP pin bar left and right
Power-Supply
alternative: use 2.54 mm long Pin Socket instad of PinHeader
In consideration of the adaptability was waived a voltage regulator.

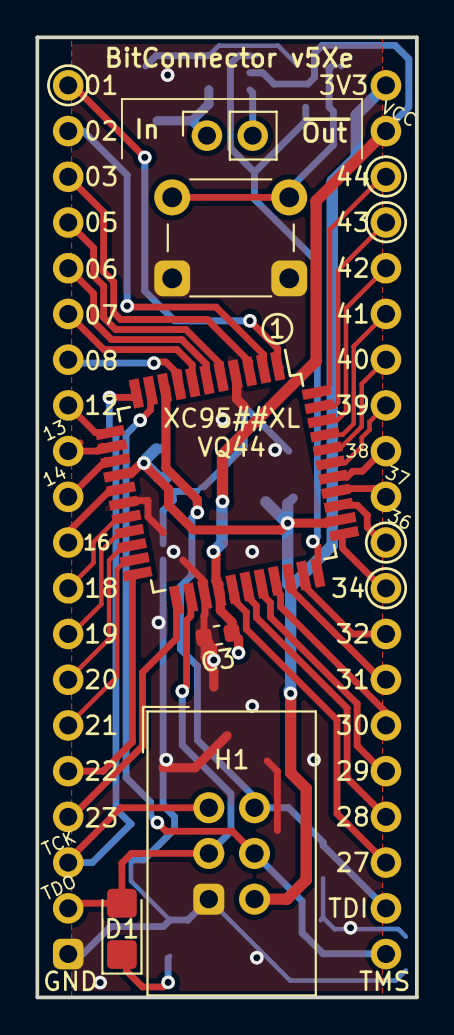
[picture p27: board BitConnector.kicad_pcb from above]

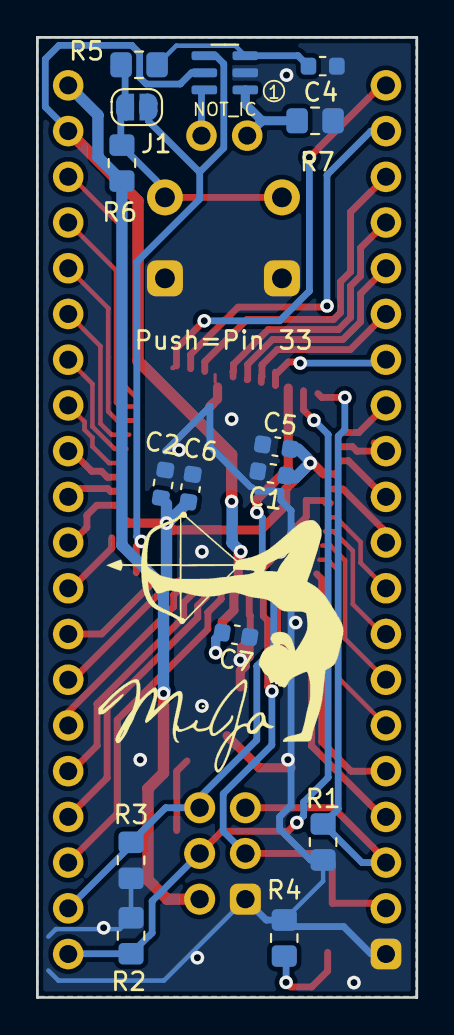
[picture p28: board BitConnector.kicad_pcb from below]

Board: 2 copper layers, 21.1 x 53.3 mm, 23 parts (17 on the bottom side), 46 nets.

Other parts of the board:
NOT_IC: 74LVC2G14; SC-74-6_1.5x2.9mm_P0.95mm

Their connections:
GND: NOT_IC.2; also elsewhere on the board
unnamed 39: NOT_IC.3; also elsewhere on the board
unnamed 40: NOT_IC.4; also elsewhere on the board
unnamed 43: NOT_IC.1; also elsewhere on the board
unnamed 44: NOT_IC.6; also elsewhere on the board
VCC: NOT_IC.5; also elsewhere on the board

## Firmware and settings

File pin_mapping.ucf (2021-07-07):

#---------------------------------------
#CPLD-DIP-Board ucf pin definitions file |
#---------------------------------------
#If you do not know what you are doing	|
#use max 3.3V for any cpld pin.			|
#---------------------------------------
#by Michael Krause

#left DIP-side

#NET	GPIO_1GCK3		LOC="1";
#NET	GPIO_2			LOC="2";
#NET	GPIO_3			LOC="3";
#NET	GPIO_5			LOC="5";
#NET	GPIO_6        		LOC="6";
#NET	GPIO_7			LOC="7";
#NET  	GPIO_8			LOC="8";
#NET  	GPIO_12			LOC="12";
#NET  	GPIO_13        		LOC="13";
#NET  	GPIO_14			LOC="14";
#NET  	GPIO_16			LOC="16";
#NET  	GPIO_18			LOC="18";
#NET  	GPIO_19        		LOC="19";
#NET  	GPIO_20			LOC="20";
#NET  	GPIO_21			LOC="21";
#NET  	GPIO_22			LOC="22";
#NET  	GPIO_23			LOC="23";
#NET  	TCK			LOC="11";
#NET  	TDO			LOC="24";

#right DIP-side
#NET  	GPIO_44GCK2		LOC="44";
#NET  	GPIO_43GCK1        	LOC="43";
#NET  	GPIO_42			LOC="42";
#NET  	GPIO_41			LOC="41";
#NET  	GPIO_40        		LOC="40";
#NET  	GPIO_39			LOC="39";
#NET  	GPIO_38			LOC="38";
#NET  	GPIO_37			LOC="37";
#NET  	GPIO_36GTS1        	LOC="36";
#NET  	GPIO_34GTS2		LOC="34";
#NET  	GPIO_32			LOC="32";
#NET  	GPIO_31			LOC="31";
#NET  	GPIO_30        		LOC="30";
#NET  	GPIO_29			LOC="29";
#NET	GPIO_28			LOC="28";
#NET	GPIO_27			LOC="27";
#NET  	TDI			LOC="9";
#NET  	TMS			LOC="10";

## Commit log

2019-10-12 Initialer Commit
    [BitConnector.kicad_pcb, BitConnector.sch]
2019-10-12 edit README - add BOM - add pin overview - edit some graphics
2019-10-21 Update und expand descriptions in the readme
2019-11-07 Introduce BitConnector_v4X - Add hardware debouncing via schmitt trigger action - The Schmnitt Triger adds another external inverter. Usable over J2. - As an alternative, add jumper to bridge the Sch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
    [BitConnector.kicad_pcb, BitConnector.sch]
2019-11-08 Correct specification in the BOM for caps
2019-11-11 Add doc, add chapters on voltage characteristics.
2019-11-26 Consider Mr Heighway Grammar suggestions.
    Insert a thank you section.
2019-11-26 Change package for 74LVC2G14 from SOT363 to SOT457
    [BitConnector.kicad_pcb, BitConnector.sch]
2019-12-18 insert merge request from mr heighway for README
2021-02-05 first attempt of the new v5X version
    details:
    - switch solder pad for resistors from 1.15mm to 1.20mm
    - add additional 10nF bypass capacitor according to
    Xilinx XAPP104 (3.0.1) specification
    - Completely new board layout created to improve
    GND and Vcc connection and suppress interference signals
    - fallback to v3X (minimal configuration) is retained
    - 74LVC2G14 (schmitt trigger) now has a better footprint
    [BitConnector.kicad_pcb, BitConnector.sch]
2021-02-05 Revise board layout
    according to suggestions for improvement, see under:
    https://www.mikrocontroller.net/topic/492067
    thx Lothar
    [BitConnector.kicad_pcb]
2021-02-07 Adjust README and graphics to the new version 5
    [BitConnector.kicad_pcb]
2021-02-07 update „Thanks to“ in README.md
2021-03-21 Complete the assembly list.
2021-04-14 Add hints to GND problems in the gck pins
2021-04-14 Specify GND issues on the GCK globally routed nets
2021-04-25 Test circuit with improved GND connection connection
    [BitConnector.kicad_pcb]
2021-05-24 Optimize the distance between the two pin headers
    [BitConnector.kicad_pcb]
2021-06-04 Expand chapter 7 on cable manufacturing
2021-06-24 Revise the concept of PCB labeling
    [BitConnector.kicad_pcb, BitConnector.sch]
2021-06-24 Change pin designation in schematic and
    - expand debouncing chapter
2021-06-24 Revised key data overview according new pin scheme
2021-06-25 add new graphics to current vers.& delete old ones
2021-06-25 Map new PCB label to table
2021-07-07 Passe die Pinzuweisung an die v5Xe Version an.
    The designation of the pins now matches the circuit diagram.

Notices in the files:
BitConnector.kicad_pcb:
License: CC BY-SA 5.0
